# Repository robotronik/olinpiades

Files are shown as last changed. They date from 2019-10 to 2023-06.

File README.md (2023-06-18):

# Git pour les yeux du char des ol'INPiade

## Installation du dépot :
Pour cloner ce dépot:
```
git clone --recurse-submodules git@github.com:robotronik/olinpiades.git
```
## pré-requis : 
 
### Programmation
- arm-none-eabi-gcc: pour compiler le programme du stm32 ainsi que ces librairies (arm-none-eabi-**** sur arch linux)
- openocd: pour envoyer le programme au stm32
- meson pour compiler
### Génération des images
- Python
### Carte élctronique : 
- kicad 5

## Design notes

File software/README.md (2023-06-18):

# Programme des matrices de LEDs pour les olinpiades
Pour cloner ce dépot:
```
git clone --recurse-submodules git@github.com:robotronik/olinpiades.git
```
## Programme du stm32
pré-requis:  
- arm-none-eabi-gcc: pour compiler le programme du stm32 ainsi que ces librairies (arm-none-eabi-**** sur arch linux)
- openocd: pour envoyer le programme au stm32
- meson pour compiler

Pour compiler les programmes:
```
make build
```
Le dossier build est alors créé. Pour envoyer le programme au stm32 (cela nécessite d'avoir installé les règles udev correctement (make install_udev)), depuis le dossier \_build:
```
ninja olinpiades.flash
```

## Programme de génération de frames
Pour tester ce qui va être afficher, depuis le dossier \_build:
```
./frames_generator/display_test
```
Si les frames ont étés modifiées (options de génération ou images d'entrée):
```
ninja regenerate_frames_files
ninja
```
Les frames sont stockées dans le fichier frames_generator/frames_definition.c . Le script python frames_generator/generator.py est en charge de créer ce fichier. Des options sont disponibles en haut de ce fichier (rotation, miroir x, miroir y, affichage du résultat appliqué à chaque image).  

Les frames sont générées à partir des images contenues dans frames_generator/images. L'ordre alphabétique des fichiers donne l'ordre des frames. La convention de nommage à respecter est la suivante: nomimage_durée_seuil.jpg (ou .png). durée est proportionnel à la durée d'apparition de l'image (entre 0 et 255) et le seuil est celui appliqué à l'image (entre 0 et 255).  

Le programme affiche la taille utilisée pour le stockage de frames (en octets). Le stm32f303k8t6 devrait pouvoir en contenir 70 au minimum.

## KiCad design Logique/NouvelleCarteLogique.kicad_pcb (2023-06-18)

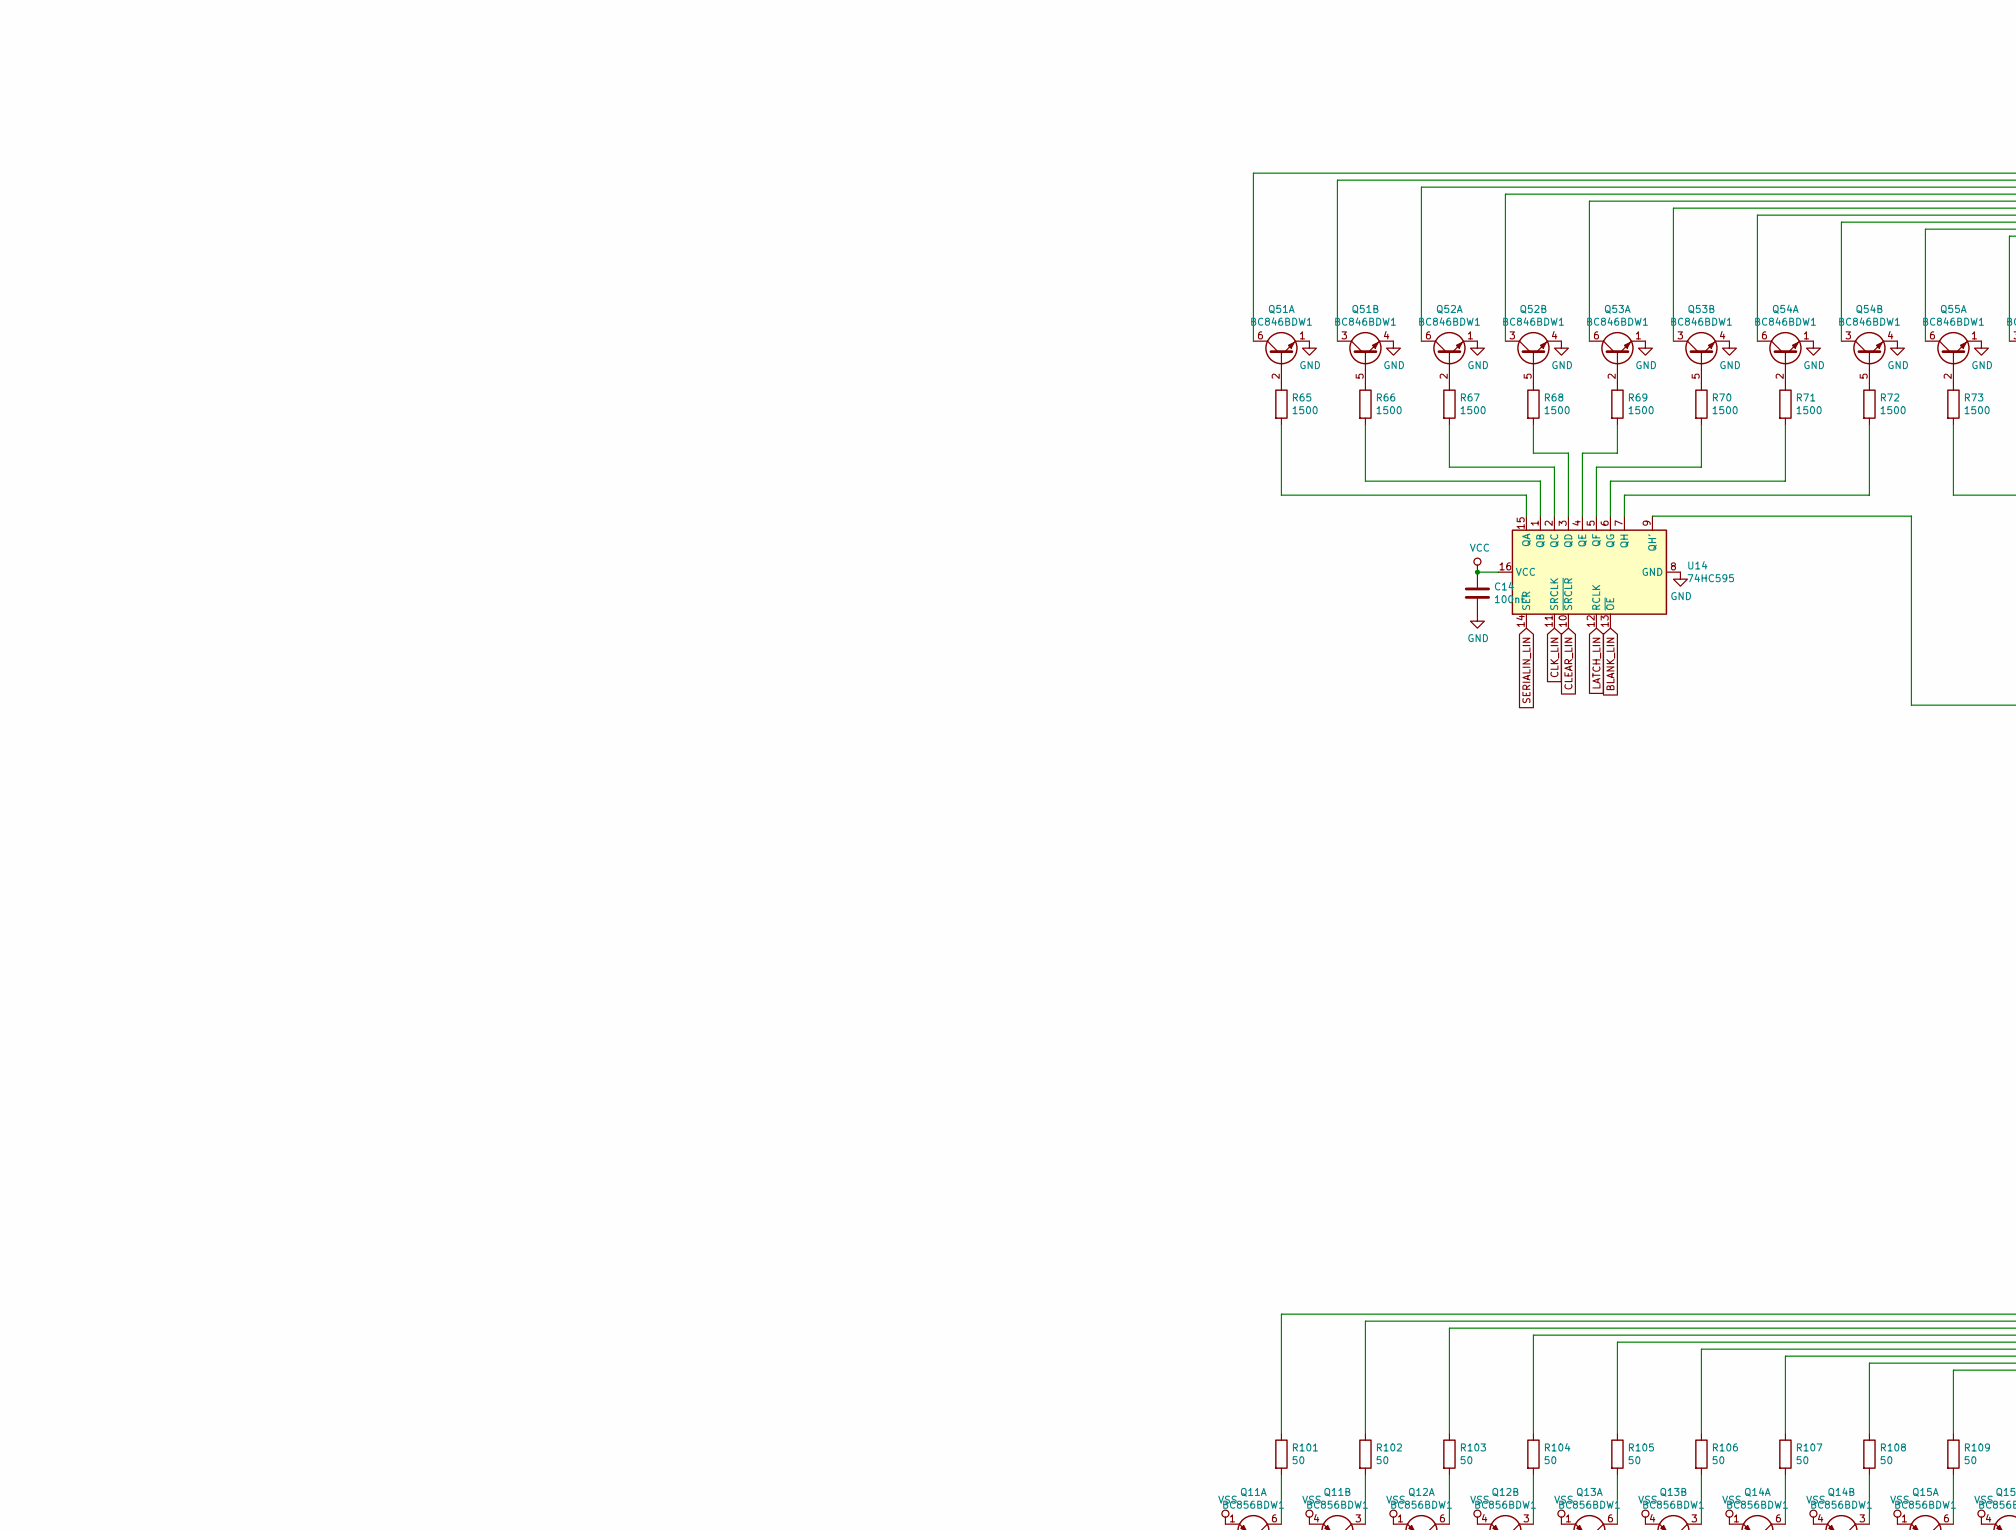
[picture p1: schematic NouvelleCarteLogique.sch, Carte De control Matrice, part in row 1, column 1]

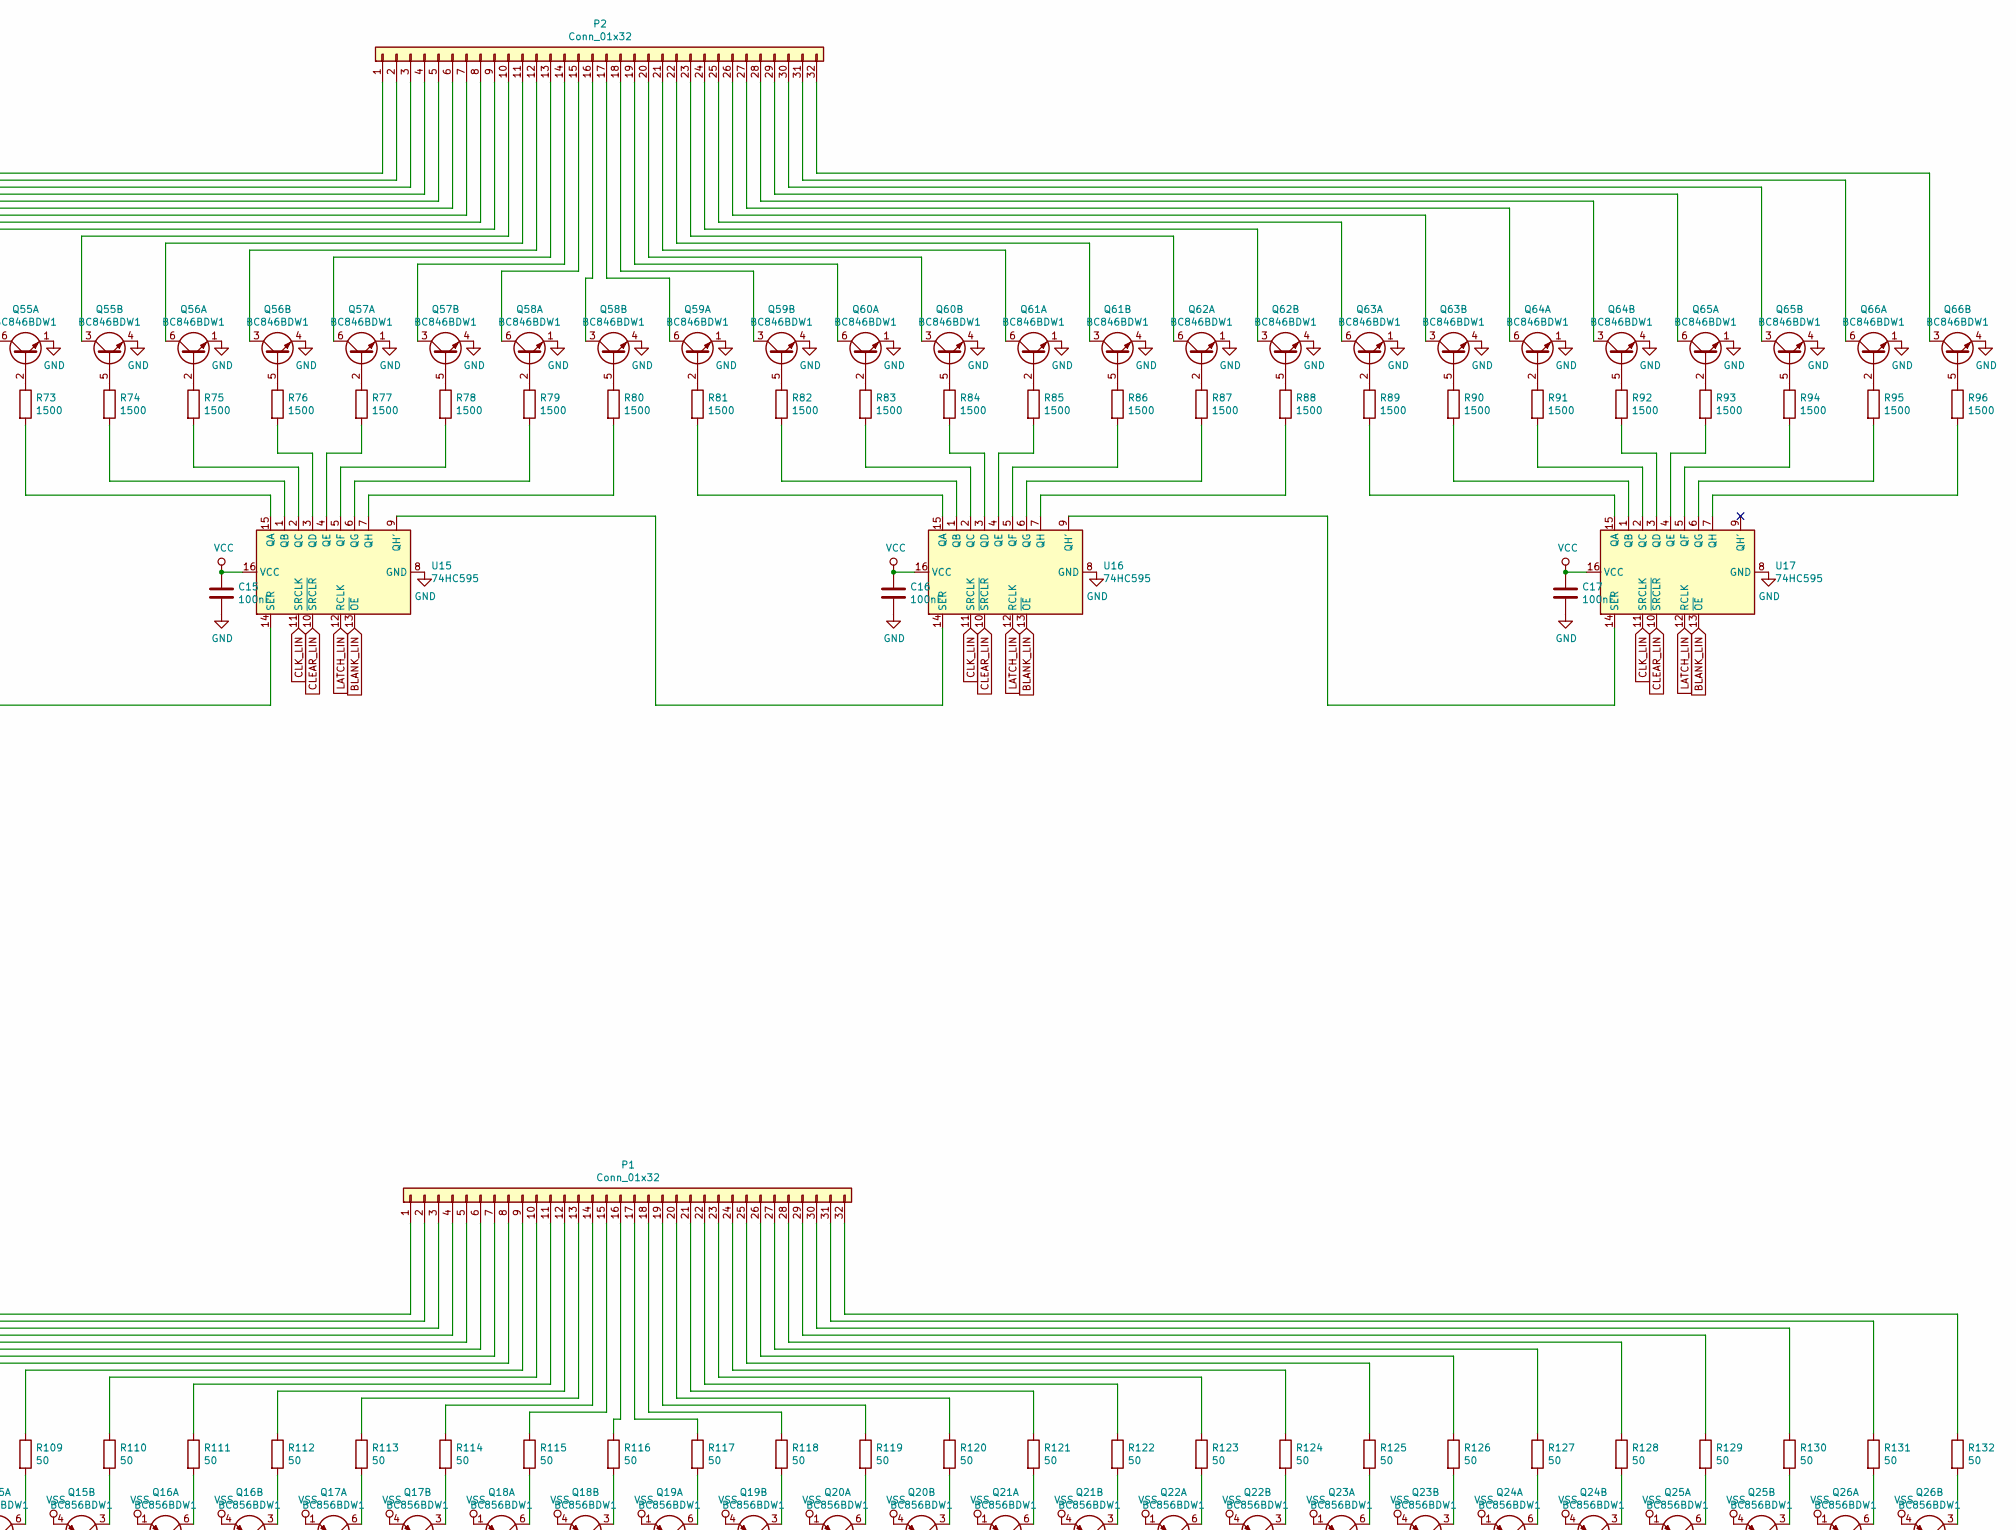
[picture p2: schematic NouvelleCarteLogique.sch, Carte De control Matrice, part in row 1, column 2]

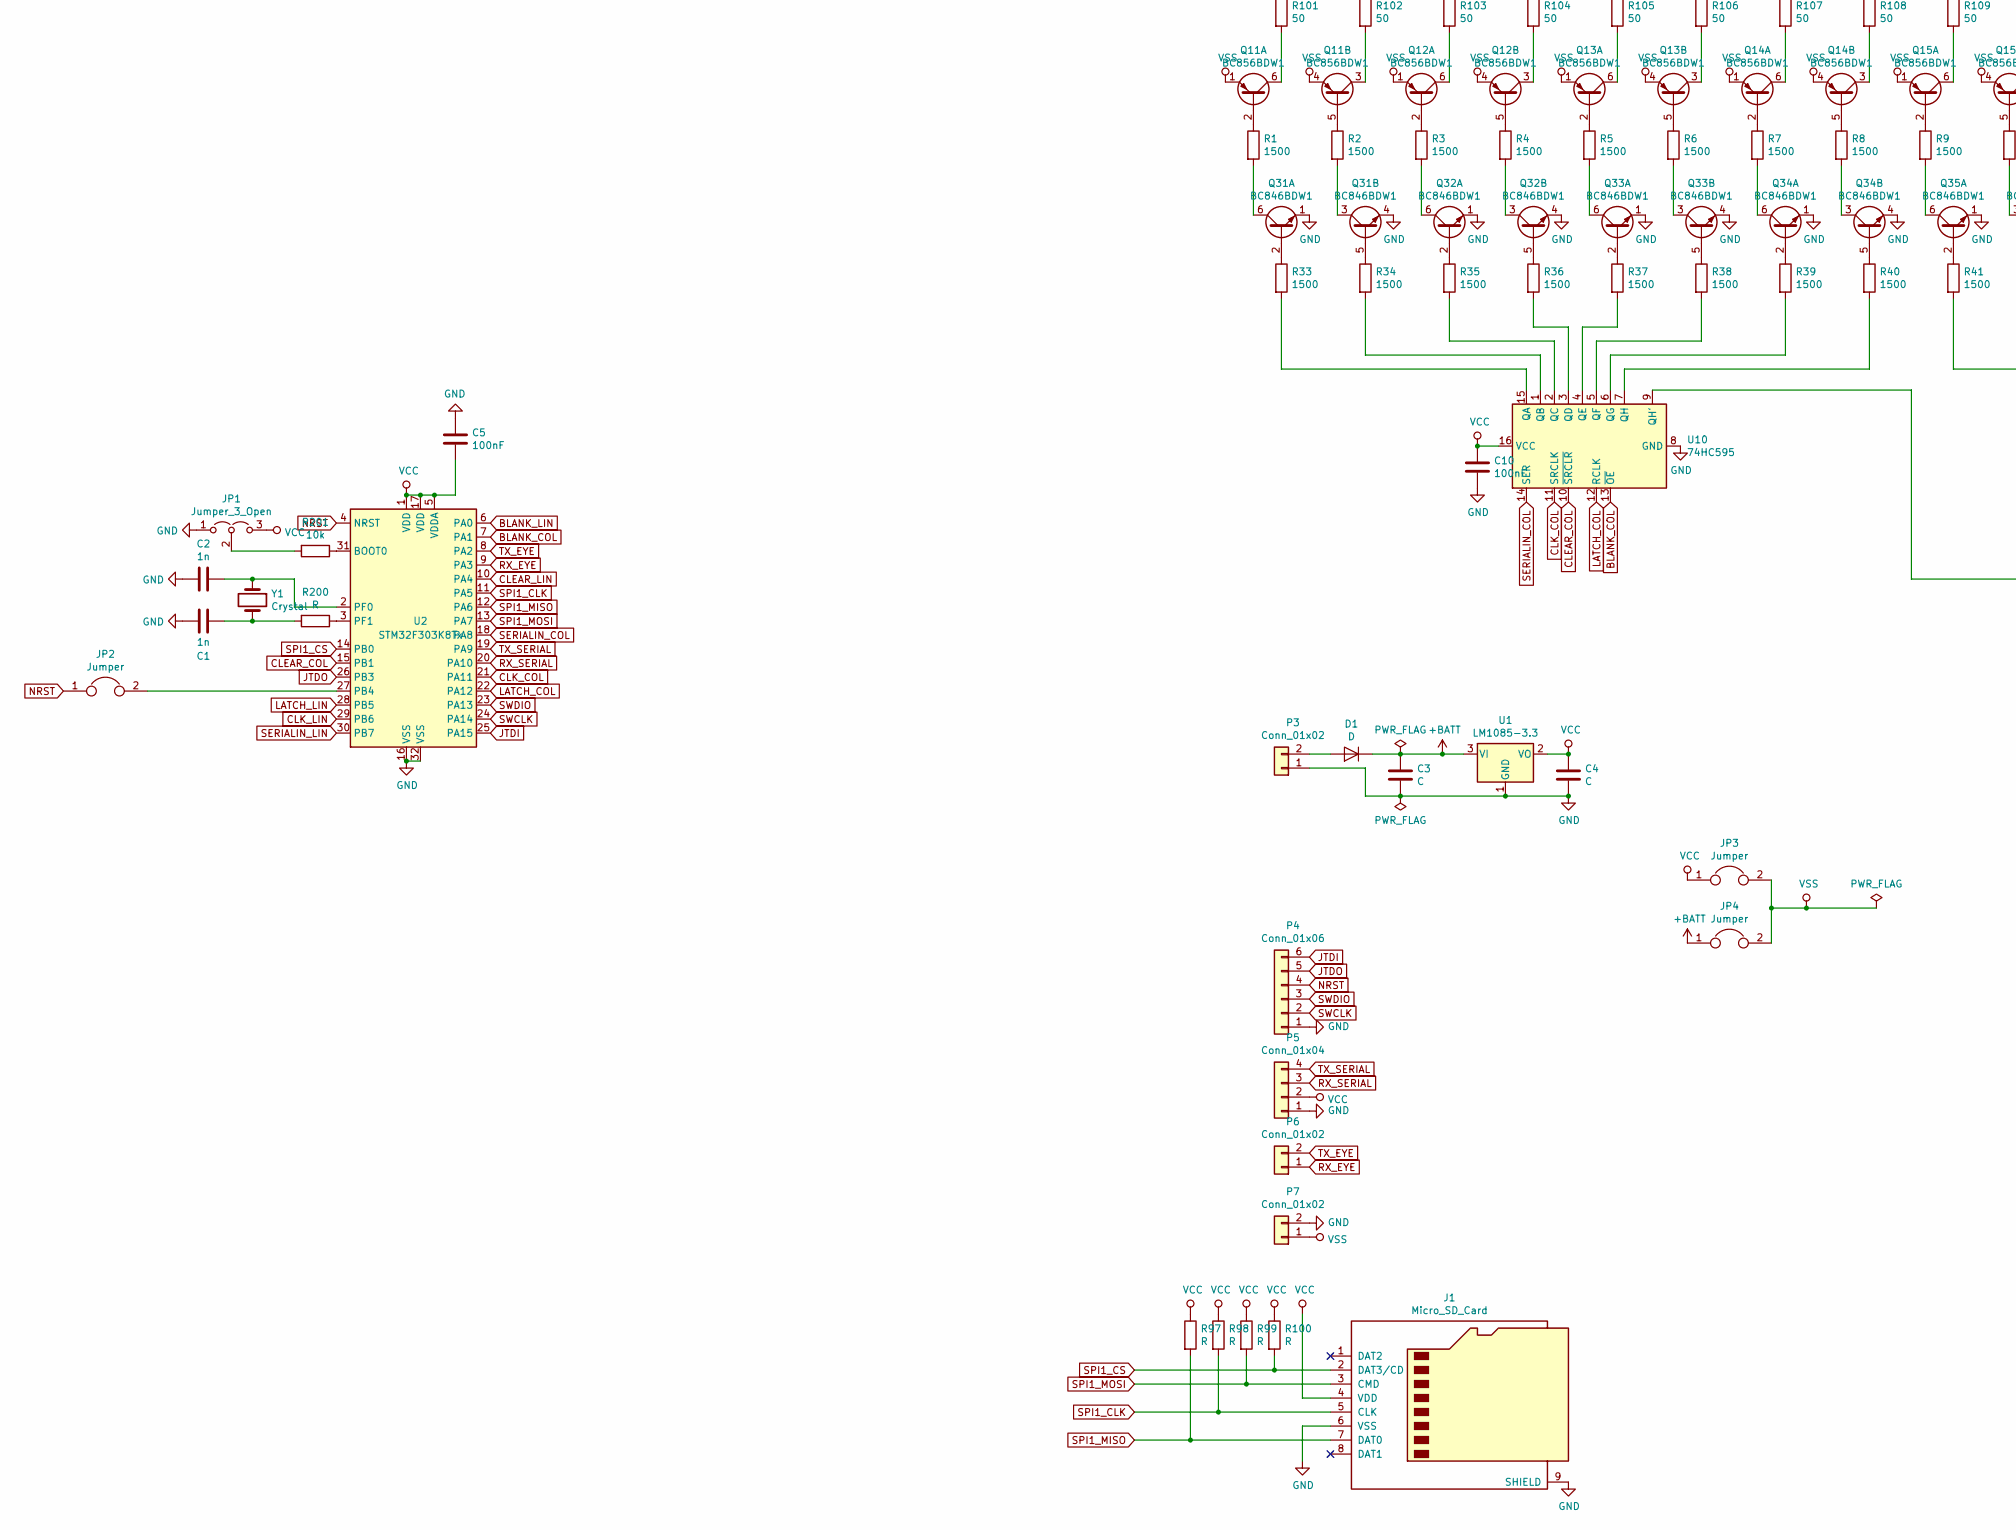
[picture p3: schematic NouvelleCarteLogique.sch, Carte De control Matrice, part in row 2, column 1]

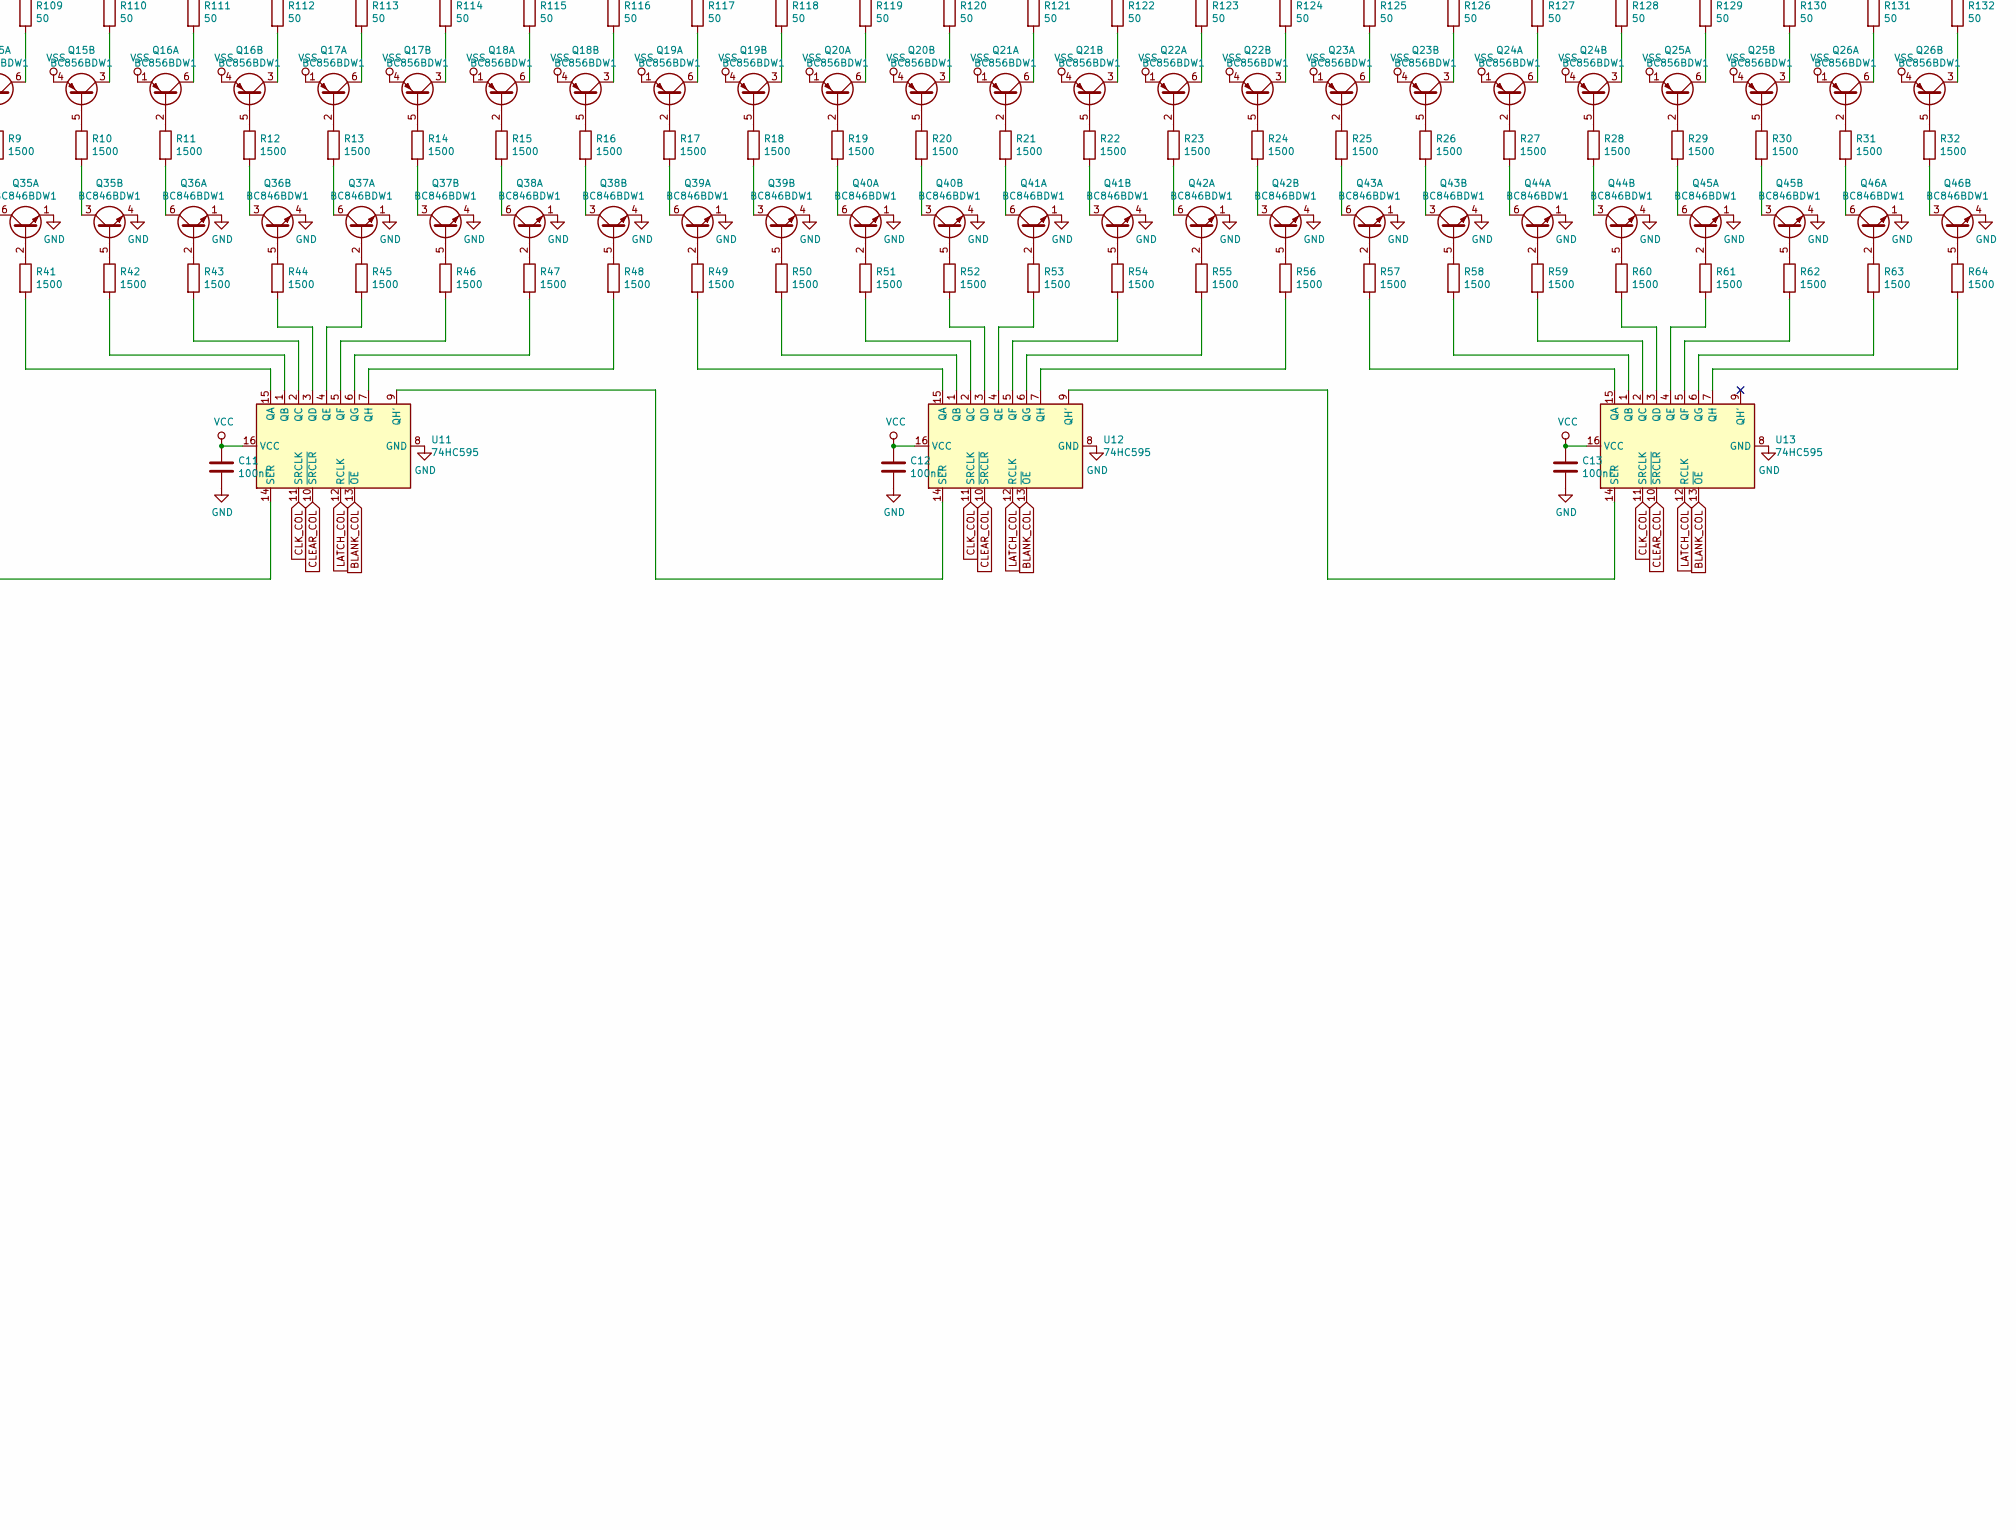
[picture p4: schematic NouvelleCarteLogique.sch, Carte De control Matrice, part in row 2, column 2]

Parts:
C1, C2: 1n; C_0805_2012Metric_Pad1.15x1.40mm_HandSolder
C3, C4: C; C_0805_2012Metric_Pad1.15x1.40mm_HandSolder
C5, C10, C11, C12, C13, C14, C15, C16, C17: 100nF; C_0805_2012Metric_Pad1.15x1.40mm_HandSolder
D1: D; D_SMA_Handsoldering
J1: Micro_SD_Card; microSD_HC_Wuerth_693072010801
JP1: Jumper_3_Open; PinHeader_1x03_P2.54mm_Vertical
JP2, JP3, JP4: Jumper; R_0805_2012Metric_Pad1.15x1.40mm_HandSolder
P1, P2: Conn_01x32; PinHeader_1x32_P2.54mm_Vertical
P3, P6, P7: Conn_01x02; TerminalBlock_bornier-2_P5.08mm
P4: Conn_01x06; PinHeader_1x06_P2.54mm_Horizontal
P5: Conn_01x04; PinHeader_1x04_P2.54mm_Horizontal
Q11, Q12, Q13, Q14, Q15, Q16, Q17, Q18, Q19, Q20, Q21, Q22, Q23, Q24, Q25, Q26: BC856BDW1; SOT-363_SC-70-6
Q31, Q32, Q33, Q34, Q35, Q36, Q37, Q38, Q39, Q40, Q41, Q42, Q43, Q44, Q45, Q46, Q51, Q52, Q53, Q54, Q55, Q56, Q57, Q58, Q59, Q60, Q61, Q62, Q63, Q64, Q65, Q66: BC846BDW1; SOT-363_SC-70-6
R1, R2, R3, R4, R5, R6, R7, R8, R9, R10, R11, R12, R13, R14, R15, R16, R17, R18, R19, R20, R21, R22, R23, R24, R25, R26, R27, R28, R29, R30, R31, R32, R33, R34, R35, R36, R37, R38, R39, R40, R41, R42, R43, R44, R45, R46, R47, R48, R49, R50, R51, R52, R53, R54, R55, R56, R57, R58, R59, R60, R61, R62, R63, R64, R65, R66, R67, R68, R69, R70, R71, R72, R73, R74, R75, R76, R77, R78, R79, R80, R81, R82, R83, R84, R85, R86, R87, R88, R89, R90, R91, R92, R93, R94, R95, R96: 1500; R_0805_2012Metric_Pad1.15x1.40mm_HandSolder
R97, R98, R99, R100, R200: R; R_0805_2012Metric_Pad1.15x1.40mm_HandSolder
R101, R102, R103, R104, R105, R106, R107, R108, R109, R110, R111, R112, R113, R114, R115, R116, R117, R118, R119, R120, R121, R122, R123, R124, R125, R126, R127, R128, R129, R130, R131, R132: 50; R_0805_2012Metric_Pad1.15x1.40mm_HandSolder
R201: 10k; R_0805_2012Metric_Pad1.15x1.40mm_HandSolder
U1: LM1085-3.3; TO-263-3_TabPin2
U2: STM32F303K8Tx; LQFP-32_7x7mm_P0.8mm
U10, U11, U12, U13, U14, U15, U16, U17: 74HC595; TSSOP-16_4.4x5mm_P0.65mm
Y1: Crystal; Crystal_HC49-4H_Vertical

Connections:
+BATT: C3.1, D1.1 (K), JP4.1, U1.3 (VI)
BLANK_COL: U2.7 (PA1), U10.13 (~OE), U11.13 (~OE), U12.13 (~OE), U13.13 (~OE)
BLANK_LIN: U2.6 (PA0), U14.13 (~OE), U15.13 (~OE), U16.13 (~OE), U17.13 (~OE)
CLEAR_COL: U2.15 (PB1), U10.10 (~SRCLR), U11.10 (~SRCLR), U12.10 (~SRCLR), U13.10 (~SRCLR)
CLEAR_LIN: U2.10 (PA4), U14.10 (~SRCLR), U15.10 (~SRCLR), U16.10 (~SRCLR), U17.10 (~SRCLR)
CLK_COL: U2.21 (PA11), U10.11 (SRCLK), U11.11 (SRCLK), U12.11 (SRCLK), U13.11 (SRCLK)
CLK_LIN: U2.29 (PB6), U14.11 (SRCLK), U15.11 (SRCLK), U16.11 (SRCLK), U17.11 (SRCLK)
GND: C1.2, C2.2, C3.2, C4.2, C5.1, C10.2, C11.2, C12.2, C13.2, C14.2, C15.2, C16.2, C17.2, J1.6 (VSS), J1.9 (SHIELD), JP1.1 (A), P3.1, P4.1, P5.1, P7.2, Q31.1 (E1), Q31.4 (E2), Q32.1 (E1), Q32.4 (E2), Q33.1 (E1), Q33.4 (E2), Q34.1 (E1), Q34.4 (E2), Q35.1 (E1), Q35.4 (E2), Q36.1 (E1), Q36.4 (E2), Q37.1 (E1), Q37.4 (E2), Q38.1 (E1), Q38.4 (E2), Q39.1 (E1), Q39.4 (E2), Q40.1 (E1), Q40.4 (E2), Q41.1 (E1), Q41.4 (E2), Q42.1 (E1), Q42.4 (E2), Q43.1 (E1), Q43.4 (E2), Q44.1 (E1), Q44.4 (E2), Q45.1 (E1), Q45.4 (E2), Q46.1 (E1), Q46.4 (E2), Q51.1 (E1), Q51.4 (E2), Q52.1 (E1), Q52.4 (E2), Q53.1 (E1), Q53.4 (E2), Q54.1 (E1), Q54.4 (E2), Q55.1 (E1), Q55.4 (E2), Q56.1 (E1), Q56.4 (E2), Q57.1 (E1), Q57.4 (E2), Q58.1 (E1), Q58.4 (E2), Q59.1 (E1), Q59.4 (E2), Q60.1 (E1), Q60.4 (E2), Q61.1 (E1), Q61.4 (E2), Q62.1 (E1), Q62.4 (E2), Q63.1 (E1), Q63.4 (E2), Q64.1 (E1), Q64.4 (E2), Q65.1 (E1), Q65.4 (E2), Q66.1 (E1), Q66.4 (E2), U1.1 (GND), U2.16 (VSS), U2.32 (VSS), U10.8 (GND), U11.8 (GND), U12.8 (GND), U13.8 (GND), U14.8 (GND), U15.8 (GND), U16.8 (GND), U17.8 (GND)
JTDI: P4.6, U2.25 (PA15)
JTDO: P4.5, U2.26 (PB3)
LATCH_COL: U2.22 (PA12), U10.12 (RCLK), U11.12 (RCLK), U12.12 (RCLK), U13.12 (RCLK)
LATCH_LIN: U2.28 (PB5), U14.12 (RCLK), U15.12 (RCLK), U16.12 (RCLK), U17.12 (RCLK)
NRST: JP2.1, P4.4, U2.4 (NRST)
unnamed: C1.1, R200.2, Y1.2
unnamed: C2.1, U2.2 (PF0), Y1.1
unnamed: D1.2 (A), P3.2
unnamed: JP1.2 (C), R201.2
unnamed: JP2.2, U2.27 (PB4)
unnamed: P1.1, R101.1
unnamed: P1.2, R102.1
unnamed: P1.3, R103.1
unnamed: P1.4, R104.1
unnamed: P1.5, R105.1
unnamed: P1.6, R106.1
unnamed: P1.7, R107.1
unnamed: P1.8, R108.1
unnamed: P1.9, R109.1
unnamed: P1.10, R110.1
unnamed: P1.11, R111.1
unnamed: P1.12, R112.1
unnamed: P1.13, R113.1
unnamed: P1.14, R114.1
unnamed: P1.15, R115.1
unnamed: P1.16, R116.1
unnamed: P1.17, R117.1
unnamed: P1.18, R118.1
unnamed: P1.19, R119.1
unnamed: P1.20, R120.1
unnamed: P1.21, R121.1
unnamed: P1.22, R122.1
unnamed: P1.23, R123.1
unnamed: P1.24, R124.1
unnamed: P1.25, R125.1
unnamed: P1.26, R126.1
unnamed: P1.27, R127.1
unnamed: P1.28, R128.1
unnamed: P1.29, R129.1
unnamed: P1.30, R130.1
unnamed: P1.31, R131.1
unnamed: P1.32, R132.1
unnamed: P2.1, Q51.6 (C1)
unnamed: P2.2, Q51.3 (C2)
unnamed: P2.3, Q52.6 (C1)
unnamed: P2.4, Q52.3 (C2)
unnamed: P2.5, Q53.6 (C1)
unnamed: P2.6, Q53.3 (C2)
unnamed: P2.7, Q54.6 (C1)
unnamed: P2.8, Q54.3 (C2)
unnamed: P2.9, Q55.6 (C1)
unnamed: P2.10, Q55.3 (C2)
unnamed: P2.11, Q56.6 (C1)
unnamed: P2.12, Q56.3 (C2)
unnamed: P2.13, Q57.6 (C1)
unnamed: P2.14, Q57.3 (C2)
unnamed: P2.15, Q58.6 (C1)
unnamed: P2.16, Q58.3 (C2)
unnamed: P2.17, Q59.6 (C1)
unnamed: P2.18, Q59.3 (C2)
unnamed: P2.19, Q60.6 (C1)
unnamed: P2.20, Q60.3 (C2)
unnamed: P2.21, Q61.6 (C1)
unnamed: P2.22, Q61.3 (C2)
unnamed: P2.23, Q62.6 (C1)
unnamed: P2.24, Q62.3 (C2)
unnamed: P2.25, Q63.6 (C1)
unnamed: P2.26, Q63.3 (C2)
unnamed: P2.27, Q64.6 (C1)
unnamed: P2.28, Q64.3 (C2)
unnamed: P2.29, Q65.6 (C1)
unnamed: P2.30, Q65.3 (C2)
unnamed: P2.31, Q66.6 (C1)
unnamed: P2.32, Q66.3 (C2)
unnamed: Q11.2 (B1), R1.1
unnamed: Q11.3 (C2), R102.2
unnamed: Q11.5 (B2), R2.1
unnamed: Q11.6 (C1), R101.2
unnamed: Q12.2 (B1), R3.1
unnamed: Q12.3 (C2), R104.2
unnamed: Q12.5 (B2), R4.1
unnamed: Q12.6 (C1), R103.2
unnamed: Q13.2 (B1), R5.1
unnamed: Q13.3 (C2), R106.2
unnamed: Q13.5 (B2), R6.1
unnamed: Q13.6 (C1), R105.2
unnamed: Q14.2 (B1), R7.1
unnamed: Q14.3 (C2), R108.2
unnamed: Q14.5 (B2), R8.1
unnamed: Q14.6 (C1), R107.2
unnamed: Q15.2 (B1), R9.1
unnamed: Q15.3 (C2), R110.2
unnamed: Q15.5 (B2), R10.1
unnamed: Q15.6 (C1), R109.2
unnamed: Q16.2 (B1), R11.1
unnamed: Q16.3 (C2), R112.2
unnamed: Q16.5 (B2), R12.1
unnamed: Q16.6 (C1), R111.2
unnamed: Q17.2 (B1), R13.1
unnamed: Q17.3 (C2), R114.2
unnamed: Q17.5 (B2), R14.1
unnamed: Q17.6 (C1), R113.2
unnamed: Q18.2 (B1), R15.1
unnamed: Q18.3 (C2), R116.2
unnamed: Q18.5 (B2), R16.1
unnamed: Q18.6 (C1), R115.2
unnamed: Q19.2 (B1), R17.1
unnamed: Q19.3 (C2), R118.2
unnamed: Q19.5 (B2), R18.1
unnamed: Q19.6 (C1), R117.2
unnamed: Q20.2 (B1), R19.1
unnamed: Q20.3 (C2), R120.2
unnamed: Q20.5 (B2), R20.1
unnamed: Q20.6 (C1), R119.2
unnamed: Q21.2 (B1), R21.1
unnamed: Q21.3 (C2), R122.2
unnamed: Q21.5 (B2), R22.1
unnamed: Q21.6 (C1), R121.2
unnamed: Q22.2 (B1), R23.1
unnamed: Q22.3 (C2), R124.2
unnamed: Q22.5 (B2), R24.1
unnamed: Q22.6 (C1), R123.2
unnamed: Q23.2 (B1), R25.1
unnamed: Q23.3 (C2), R126.2
unnamed: Q23.5 (B2), R26.1
unnamed: Q23.6 (C1), R125.2
unnamed: Q24.2 (B1), R27.1
unnamed: Q24.3 (C2), R128.2
unnamed: Q24.5 (B2), R28.1
unnamed: Q24.6 (C1), R127.2
unnamed: Q25.2 (B1), R29.1
unnamed: Q25.3 (C2), R130.2
unnamed: Q25.5 (B2), R30.1
unnamed: Q25.6 (C1), R129.2
unnamed: Q26.2 (B1), R31.1
unnamed: Q26.3 (C2), R132.2
unnamed: Q26.5 (B2), R32.1
unnamed: Q26.6 (C1), R131.2
unnamed: Q31.2 (B1), R33.1
unnamed: Q31.3 (C2), R2.2
unnamed: Q31.5 (B2), R34.1
unnamed: Q31.6 (C1), R1.2
unnamed: Q32.2 (B1), R35.1
unnamed: Q32.3 (C2), R4.2
unnamed: Q32.5 (B2), R36.1
unnamed: Q32.6 (C1), R3.2
unnamed: Q33.2 (B1), R37.1
unnamed: Q33.3 (C2), R6.2
unnamed: Q33.5 (B2), R38.1
unnamed: Q33.6 (C1), R5.2
unnamed: Q34.2 (B1), R39.1
unnamed: Q34.3 (C2), R8.2
unnamed: Q34.5 (B2), R40.1
unnamed: Q34.6 (C1), R7.2
unnamed: Q35.2 (B1), R41.1
unnamed: Q35.3 (C2), R10.2
unnamed: Q35.5 (B2), R42.1
unnamed: Q35.6 (C1), R9.2
unnamed: Q36.2 (B1), R43.1
unnamed: Q36.3 (C2), R12.2
unnamed: Q36.5 (B2), R44.1
unnamed: Q36.6 (C1), R11.2
unnamed: Q37.2 (B1), R45.1
unnamed: Q37.3 (C2), R14.2
unnamed: Q37.5 (B2), R46.1
unnamed: Q37.6 (C1), R13.2
unnamed: Q38.2 (B1), R47.1
unnamed: Q38.3 (C2), R16.2
unnamed: Q38.5 (B2), R48.1
unnamed: Q38.6 (C1), R15.2
unnamed: Q39.2 (B1), R49.1
unnamed: Q39.3 (C2), R18.2
unnamed: Q39.5 (B2), R50.1
unnamed: Q39.6 (C1), R17.2
unnamed: Q40.2 (B1), R51.1
unnamed: Q40.3 (C2), R20.2
unnamed: Q40.5 (B2), R52.1
unnamed: Q40.6 (C1), R19.2
unnamed: Q41.2 (B1), R53.1
unnamed: Q41.3 (C2), R22.2
unnamed: Q41.5 (B2), R54.1
unnamed: Q41.6 (C1), R21.2
unnamed: Q42.2 (B1), R55.1
unnamed: Q42.3 (C2), R24.2
unnamed: Q42.5 (B2), R56.1
unnamed: Q42.6 (C1), R23.2
unnamed: Q43.2 (B1), R57.1
unnamed: Q43.3 (C2), R26.2
unnamed: Q43.5 (B2), R58.1
unnamed: Q43.6 (C1), R25.2
unnamed: Q44.2 (B1), R59.1
unnamed: Q44.3 (C2), R28.2
unnamed: Q44.5 (B2), R60.1
unnamed: Q44.6 (C1), R27.2
unnamed: Q45.2 (B1), R61.1
unnamed: Q45.3 (C2), R30.2
unnamed: Q45.5 (B2), R62.1
unnamed: Q45.6 (C1), R29.2
unnamed: Q46.2 (B1), R63.1
unnamed: Q46.3 (C2), R32.2
unnamed: Q46.5 (B2), R64.1
unnamed: Q46.6 (C1), R31.2
unnamed: Q51.2 (B1), R65.1
unnamed: Q51.5 (B2), R66.1
unnamed: Q52.2 (B1), R67.1
unnamed: Q52.5 (B2), R68.1
unnamed: Q53.2 (B1), R69.1
unnamed: Q53.5 (B2), R70.1
unnamed: Q54.2 (B1), R71.1
unnamed: Q54.5 (B2), R72.1
unnamed: Q55.2 (B1), R73.1
unnamed: Q55.5 (B2), R74.1
unnamed: Q56.2 (B1), R75.1
unnamed: Q56.5 (B2), R76.1
unnamed: Q57.2 (B1), R77.1
unnamed: Q57.5 (B2), R78.1
unnamed: Q58.2 (B1), R79.1
unnamed: Q58.5 (B2), R80.1
unnamed: Q59.2 (B1), R81.1
unnamed: Q59.5 (B2), R82.1
unnamed: Q60.2 (B1), R83.1
unnamed: Q60.5 (B2), R84.1
unnamed: Q61.2 (B1), R85.1
unnamed: Q61.5 (B2), R86.1
unnamed: Q62.2 (B1), R87.1
unnamed: Q62.5 (B2), R88.1
unnamed: Q63.2 (B1), R89.1
unnamed: Q63.5 (B2), R90.1
unnamed: Q64.2 (B1), R91.1
unnamed: Q64.5 (B2), R92.1
unnamed: Q65.2 (B1), R93.1
unnamed: Q65.5 (B2), R94.1
unnamed: Q66.2 (B1), R95.1
unnamed: Q66.5 (B2), R96.1
unnamed: R33.2, U10.15 (QA)
unnamed: R34.2, U10.1 (QB)
unnamed: R35.2, U10.2 (QC)
unnamed: R36.2, U10.3 (QD)
unnamed: R37.2, U10.4 (QE)
unnamed: R38.2, U10.5 (QF)
unnamed: R39.2, U10.6 (QG)
unnamed: R40.2, U10.7 (QH)
unnamed: R41.2, U11.15 (QA)
unnamed: R42.2, U11.1 (QB)
unnamed: R43.2, U11.2 (QC)
unnamed: R44.2, U11.3 (QD)
unnamed: R45.2, U11.4 (QE)
unnamed: R46.2, U11.5 (QF)
unnamed: R47.2, U11.6 (QG)
unnamed: R48.2, U11.7 (QH)
unnamed: R49.2, U12.15 (QA)
unnamed: R50.2, U12.1 (QB)
unnamed: R51.2, U12.2 (QC)
unnamed: R52.2, U12.3 (QD)
unnamed: R53.2, U12.4 (QE)
unnamed: R54.2, U12.5 (QF)
unnamed: R55.2, U12.6 (QG)
unnamed: R56.2, U12.7 (QH)
unnamed: R57.2, U13.15 (QA)
unnamed: R58.2, U13.1 (QB)
unnamed: R59.2, U13.2 (QC)
unnamed: R60.2, U13.3 (QD)
unnamed: R61.2, U13.4 (QE)
unnamed: R62.2, U13.5 (QF)
unnamed: R63.2, U13.6 (QG)
unnamed: R64.2, U13.7 (QH)
unnamed: R65.2, U14.15 (QA)
unnamed: R66.2, U14.1 (QB)
unnamed: R67.2, U14.2 (QC)
unnamed: R68.2, U14.3 (QD)
unnamed: R69.2, U14.4 (QE)
unnamed: R70.2, U14.5 (QF)
unnamed: R71.2, U14.6 (QG)
unnamed: R72.2, U14.7 (QH)
unnamed: R73.2, U15.15 (QA)
unnamed: R74.2, U15.1 (QB)
unnamed: R75.2, U15.2 (QC)
unnamed: R76.2, U15.3 (QD)
unnamed: R77.2, U15.4 (QE)
unnamed: R78.2, U15.5 (QF)
unnamed: R79.2, U15.6 (QG)
unnamed: R80.2, U15.7 (QH)
unnamed: R81.2, U16.15 (QA)
unnamed: R82.2, U16.1 (QB)
unnamed: R83.2, U16.2 (QC)
unnamed: R84.2, U16.3 (QD)
unnamed: R85.2, U16.4 (QE)
unnamed: R86.2, U16.5 (QF)
unnamed: R87.2, U16.6 (QG)
unnamed: R88.2, U16.7 (QH)
unnamed: R89.2, U17.15 (QA)
unnamed: R90.2, U17.1 (QB)
unnamed: R91.2, U17.2 (QC)
unnamed: R92.2, U17.3 (QD)
unnamed: R93.2, U17.4 (QE)
unnamed: R94.2, U17.5 (QF)
unnamed: R95.2, U17.6 (QG)
unnamed: R96.2, U17.7 (QH)
unnamed: R200.1, U2.3 (PF1)
unnamed: R201.1, U2.31 (BOOT0)
unnamed: U10.9 (QH'), U11.14 (SER)
unnamed: U11.9 (QH'), U12.14 (SER)
unnamed: U12.9 (QH'), U13.14 (SER)
unnamed: U14.9 (QH'), U15.14 (SER)
unnamed: U15.9 (QH'), U16.14 (SER)
unnamed: U16.9 (QH'), U17.14 (SER)
RX_EYE: P6.1, U2.9 (PA3)
RX_SERIAL: P5.3, U2.20 (PA10)
SERIALIN_COL: U2.18 (PA8), U10.14 (SER)
SERIALIN_LIN: U2.30 (PB7), U14.14 (SER)
SPI1_CLK: J1.5 (CLK), R98.2, U2.11 (PA5)
SPI1_CS: J1.2 (DAT3/CD), R100.2, U2.14 (PB0)
SPI1_MISO: J1.7 (DAT0), R97.2, U2.12 (PA6)
SPI1_MOSI: J1.3 (CMD), R99.2, U2.13 (PA7)
SWCLK: P4.2, U2.24 (PA14)
SWDIO: P4.3, U2.23 (PA13)
TX_EYE: P6.2, U2.8 (PA2)
TX_SERIAL: P5.4, U2.19 (PA9)
VCC: C4.1, C5.2, C10.1, C11.1, C12.1, C13.1, C14.1, C15.1, C16.1, C17.1, J1.4 (VDD), JP1.3 (B), JP3.1, P5.2, R97.1, R98.1, R99.1, R100.1, U1.2 (VO), U2.1 (VDD), U2.5 (VDDA), U2.17 (VDD), U10.16 (VCC), U11.16 (VCC), U12.16 (VCC), U13.16 (VCC), U14.16 (VCC), U15.16 (VCC), U16.16 (VCC), U17.16 (VCC)
VSS: JP3.2, JP4.2, P7.1, Q11.1 (E1), Q11.4 (E2), Q12.1 (E1), Q12.4 (E2), Q13.1 (E1), Q13.4 (E2), Q14.1 (E1), Q14.4 (E2), Q15.1 (E1), Q15.4 (E2), Q16.1 (E1), Q16.4 (E2), Q17.1 (E1), Q17.4 (E2), Q18.1 (E1), Q18.4 (E2), Q19.1 (E1), Q19.4 (E2), Q20.1 (E1), Q20.4 (E2), Q21.1 (E1), Q21.4 (E2), Q22.1 (E1), Q22.4 (E2), Q23.1 (E1), Q23.4 (E2), Q24.1 (E1), Q24.4 (E2), Q25.1 (E1), Q25.4 (E2), Q26.1 (E1), Q26.4 (E2)

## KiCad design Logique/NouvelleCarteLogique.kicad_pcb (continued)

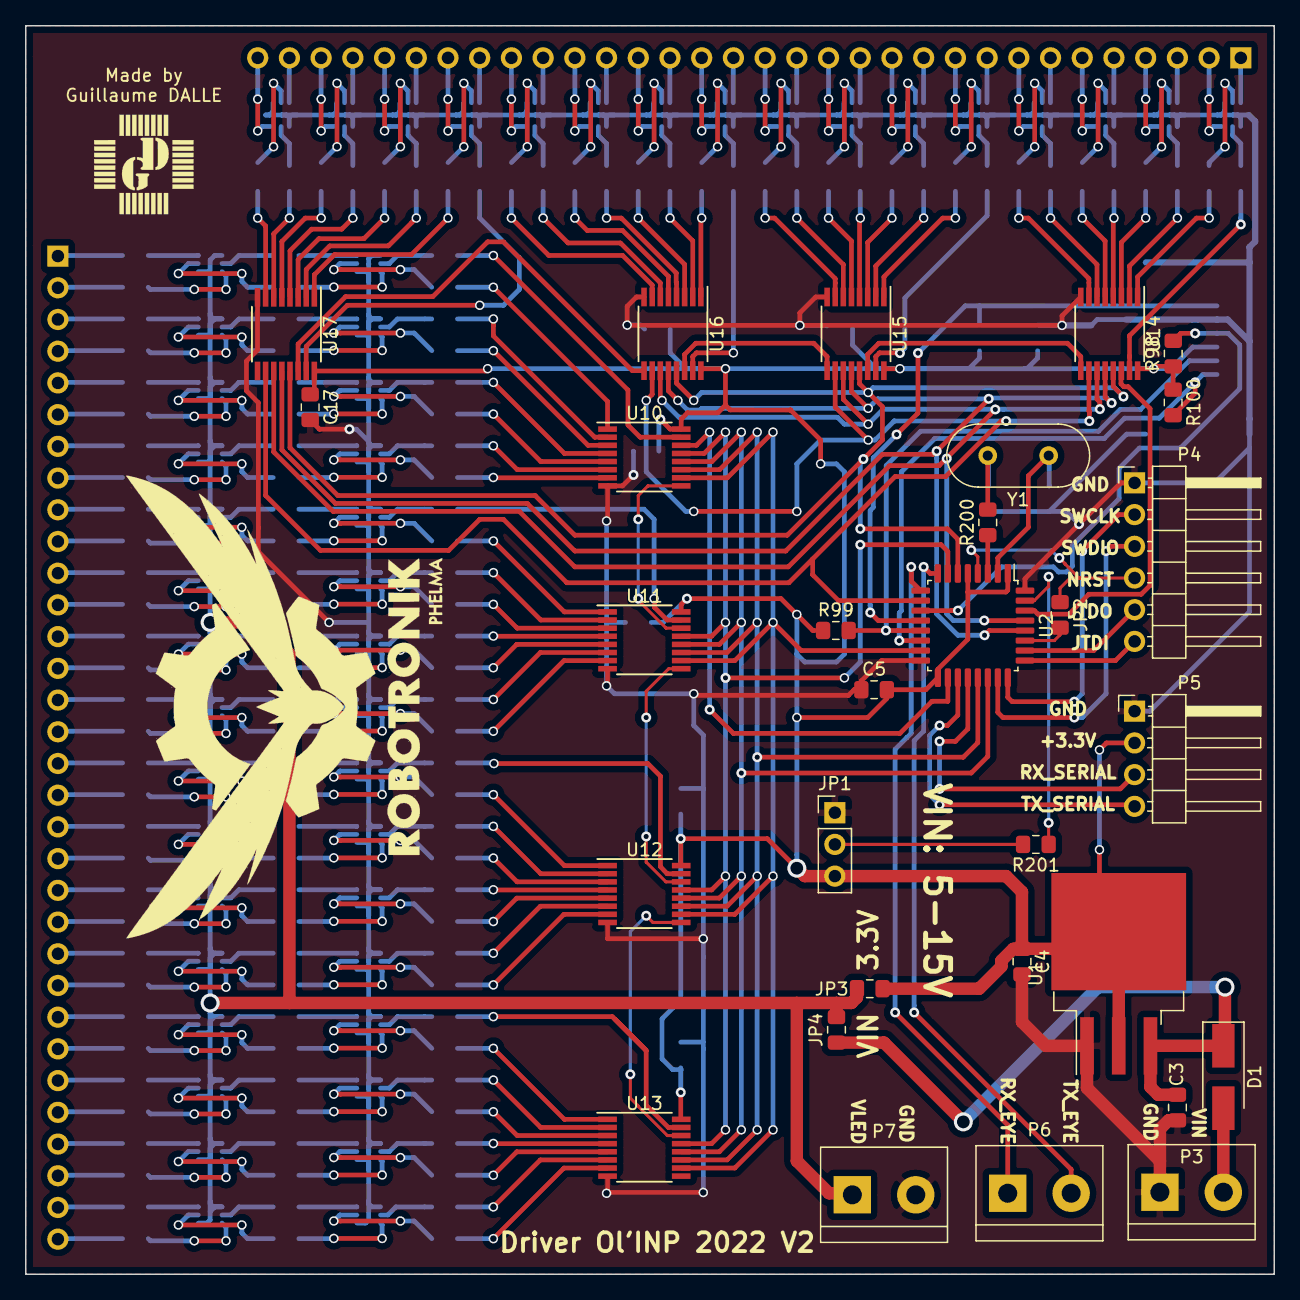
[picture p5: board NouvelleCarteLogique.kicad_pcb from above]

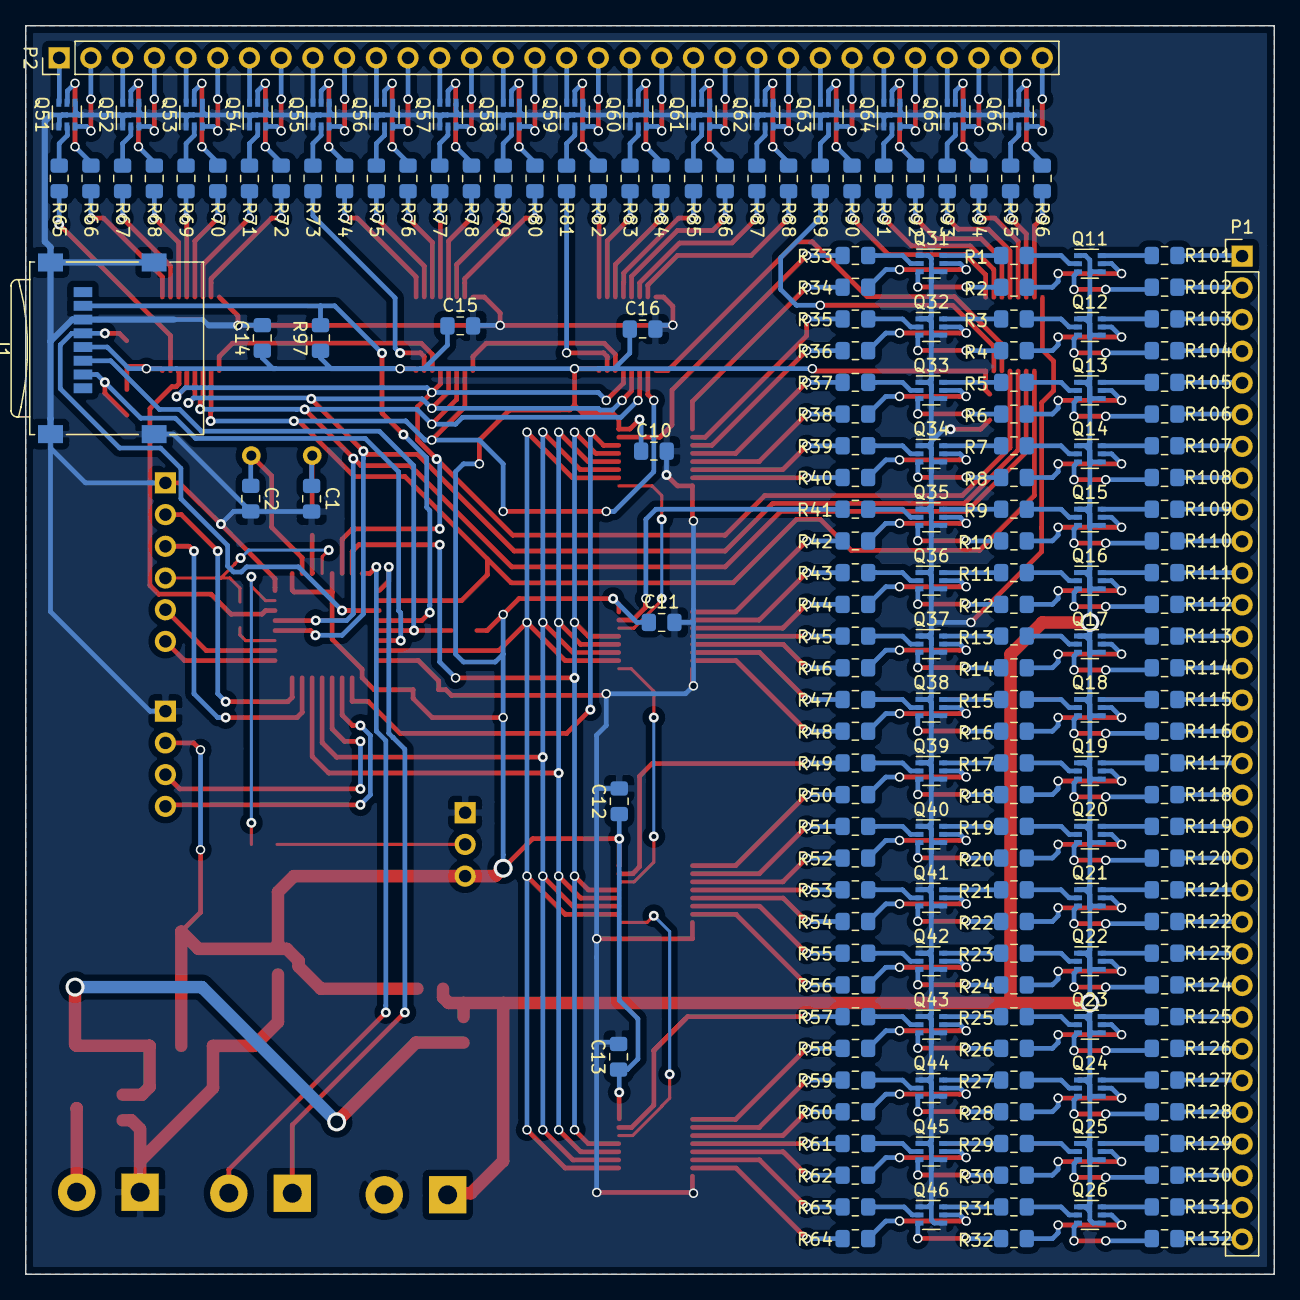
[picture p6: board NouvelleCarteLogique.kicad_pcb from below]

Board: 2 copper layers, 100.0 x 100.0 mm, 219 parts (189 on the bottom side), 328 nets.

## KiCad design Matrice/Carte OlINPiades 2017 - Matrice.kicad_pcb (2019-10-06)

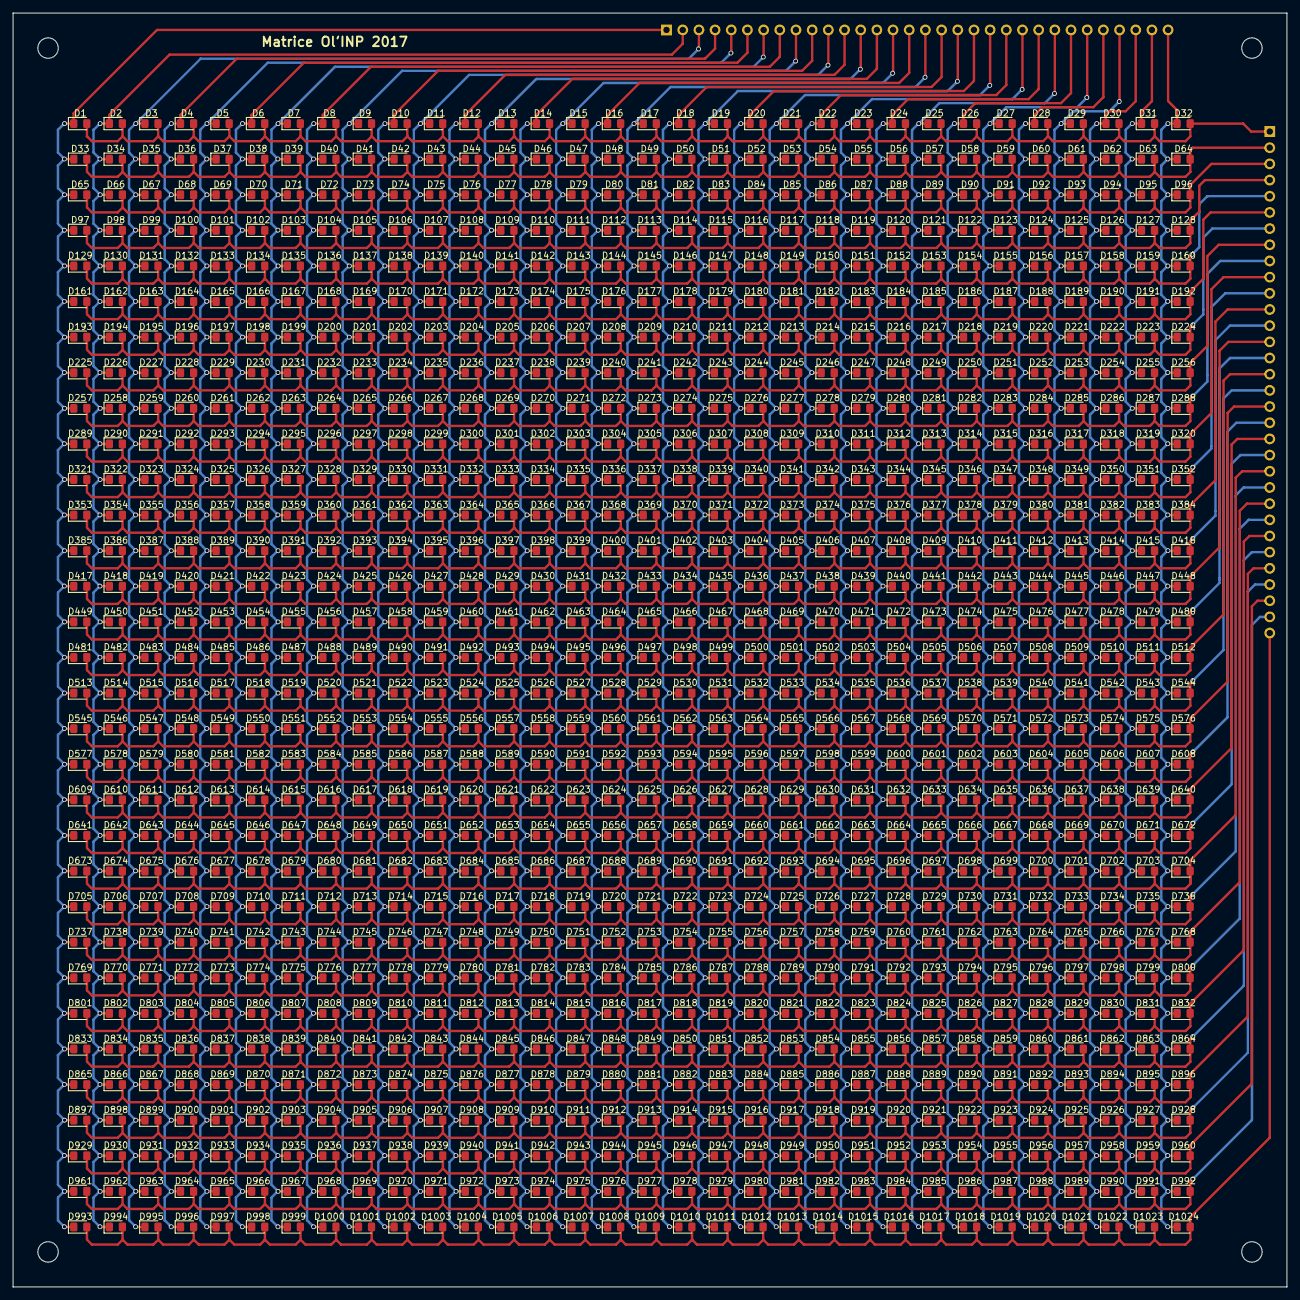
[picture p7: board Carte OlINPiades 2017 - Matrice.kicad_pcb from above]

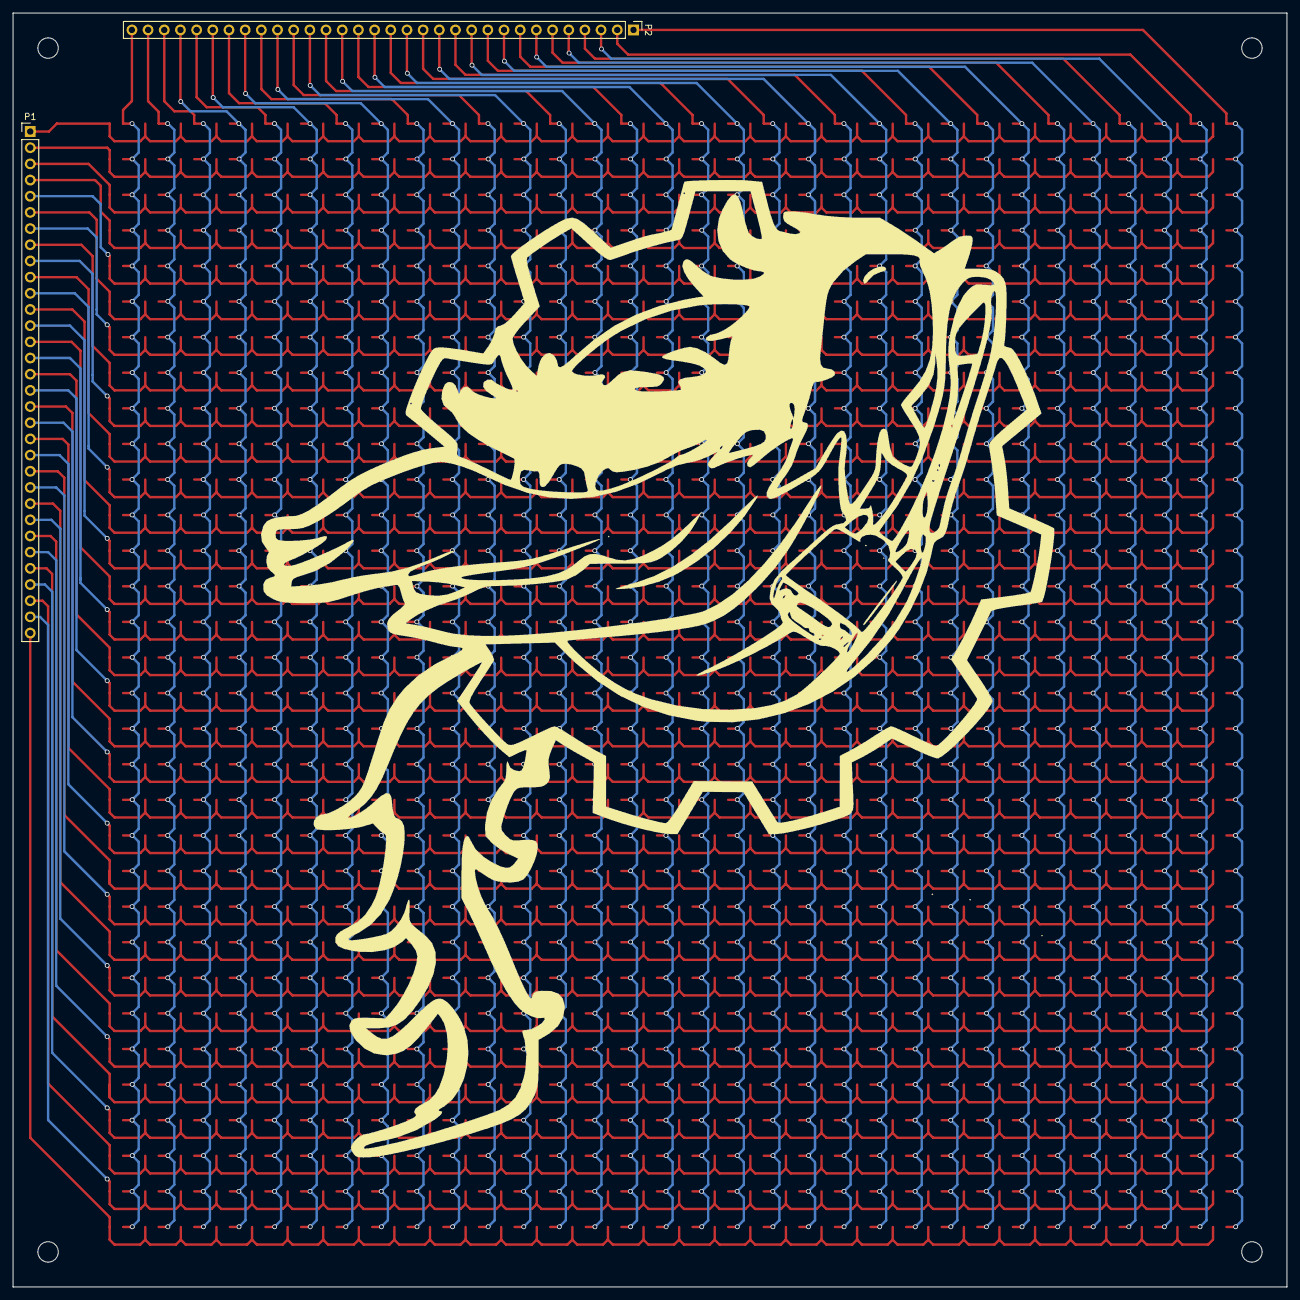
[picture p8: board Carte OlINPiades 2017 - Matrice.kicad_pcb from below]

Board: 2 copper layers, 200.0 x 200.0 mm, 1031 parts (3 on the bottom side), 64 nets.

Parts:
D1, D2, D3, D4, D5, D6, D7, D8, D9, D10, D11, D12, D13, D14, D15, D16, D17, D18, D19, D20, D21, D22, D23, D24, D25, D26, D27, D28, D29, D30, D31, D32, D33, D34, D35, D36, D37, D38, D39, D40, D41, D42, D43, D44, D45, D46, D47, D48, D49, D50, D51, D52, D53, D54, D55, D56, D57, D58, D59, D60, D61, D62, D63, D64, D65, D66, D67, D68, D69, D70, D71, D72, D73, D74, D75, D76, D77, D78, D79, D80, D81, D82, D83, D84, D85, D86, D87, D88, D89, D90, D91, D92, D93, D94, D95, D96, D97, D98, D99, D100, D101, D102, D103, D104, D105, D106, D107, D108, D109, D110, D111, D112, D113, D114, D115, D116, D117, D118, D119, D120, D121, D122, D123, D124, D125, D126, D127, D128, D129, D130, D131, D132, D133, D134, D135, D136, D137, D138, D139, D140, D141, D142, D143, D144, D145, D146, D147, D148, D149, D150, D151, D152, D153, D154, D155, D156, D157, D158, D159, D160, D161, D162, D163, D164, D165, D166, D167, D168, D169, D170, D171, D172, D173, D174, D175, D176, D177, D178, D179, D180, D181, D182, D183, D184, D185, D186, D187, D188, D189, D190, D191, D192, D193, D194, D195, D196, D197, D198, D199, D200, D201, D202, D203, D204, D205, D206, D207, D208, D209, D210, D211, D212, D213, D214, D215, D216, D217, D218, D219, D220, D221, D222, D223, D224, D225, D226, D227, D228, D229, D230, D231, D232, D233, D234, D235, D236, D237, D238, D239, D240, D241, D242, D243, D244, D245, D246, D247, D248, D249, D250, D251, D252, D253, D254, D255, D256, D257, D258, D259, D260, D261, D262, D263, D264, D265, D266, D267, D268, D269, D270, D271, D272, D273, D274, D275, D276, D277, D278, D279, D280, D281, D282, D283, D284, D285, D286, D287, D288, D289, D290, D291, D292, D293, D294, D295, D296, D297, D298, D299, D300, D301, D302, D303, D304, D305, D306, D307, D308, D309, D310, D311, D312, D313, D314, D315, D316, D317, D318, D319, D320, D321, D322, D323, D324, D325, D326, D327, D328, D329, D330, D331, D332, D333, D334, D335, D336, D337, D338, D339, D340, D341, D342, D343, D344, D345, D346, D347, D348, D349, D350, D351, D352, D353, D354, D355, D356, D357, D358, D359, D360, D361, D362, D363, D364, D365, D366, D367, D368, D369, D370, D371, D372, D373, D374, D375, D376, D377, D378, D379, D380, D381, D382, D383, D384, D385, D386, D387, D388, D389, D390, D391, D392, D393, D394, D395, D396, D397, D398, D399, D400, D401, D402, D403, D404, D405, D406, D407, D408, D409, D410, D411, D412, D413, D414, D415, D416, D417, D418, D419, D420, D421, D422, D423, D424, D425, D426, D427, D428, D429, D430, D431, D432, D433, D434, D435, D436, D437, D438, D439, D440, D441, D442, D443, D444, D445, D446, D447, D448, D449, D450, D451, D452, D453, D454, D455, D456, D457, D458, D459, D460, D461, D462, D463, D464, D465, D466, D467, D468, D469, D470, D471, D472, D473, D474, D475, D476, D477, D478, D479, D480, D481, D482, D483, D484, D485, D486, D487, D488, D489, D490, D491, D492, D493, D494, D495, D496, D497, D498, D499, D500, D501, D502, D503, D504, D505, D506, D507, D508, D509, D510, D511, D512, D513, D514, D515, D516, D517, D518, D519, D520, D521, D522, D523, D524, D525, D526, D527, D528, D529, D530, D531, D532, D533, D534, D535, D536, D537, D538, D539, D540, D541, D542, D543, D544, D545, D546, D547, D548, D549, D550, D551, D552, D553, D554, D555, D556, D557, D558, D559, D560, D561, D562, D563, D564, D565, D566, D567, D568, D569, D570, D571, D572, D573, D574, D575, D576, D577, D578, D579, D580, D581, D582, D583, D584, D585, D586, D587, D588, D589, D590, D591, D592, D593, D594, D595, D596, D597, D598, D599, D600, D601, D602, D603, D604, D605, D606, D607, D608, D609, D610, D611, D612, D613, D614, D615, D616, D617, D618, D619, D620, D621, D622, D623, D624, D625, D626, D627, D628, D629, D630, D631, D632, D633, D634, D635, D636, D637, D638, D639, D640, D641, D642, D643, D644, D645, D646, D647, D648, D649, D650, D651, D652, D653, D654, D655, D656, D657, D658, D659, D660, D661, D662, D663, D664, D665, D666, D667, D668, D669, D670, D671, D672, D673, D674, D675, D676, D677, D678, D679, D680, D681, D682, D683, D684, D685, D686, D687, D688, D689, D690, D691, D692, D693, D694, D695, D696, D697, D698, D699, D700, D701, D702, D703, D704, D705, D706, D707, D708, D709, D710, D711, D712, D713, D714, D715, D716, D717, D718, D719, D720, D721, D722, D723, D724, D725, D726, D727, D728, D729, D730, D731, D732, D733, D734, D735, D736, D737, D738, D739, D740, D741, D742, D743, D744, D745, D746, D747, D748, D749, D750, D751, D752, D753, D754, D755, D756, D757, D758, D759, D760, D761, D762, D763, D764, D765, D766, D767, D768, D769, D770, D771, D772, D773, D774, D775, D776, D777, D778, D779, D780, D781, D782, D783, D784, D785, D786, D787, D788, D789, D790, D791, D792, D793, D794, D795, D796, D797, D798, D799, D800, D801, D802, D803, D804, D805, D806, D807, D808, D809, D810, D811, D812, D813, D814, D815, D816, D817, D818, D819, D820, D821, D822, D823, D824, D825, D826, D827, D828, D829, D830, D831, D832, D833, D834, D835, D836, D837, D838, D839, D840, D841, D842, D843, D844, D845, D846, D847, D848, D849, D850, D851, D852, D853, D854, D855, D856, D857, D858, D859, D860, D861, D862, D863, D864, D865, D866, D867, D868, D869, D870, D871, D872, D873, D874, D875, D876, D877, D878, D879, D880, D881, D882, D883, D884, D885, D886, D887, D888, D889, D890, D891, D892, D893, D894, D895, D896, D897, D898, D899, D900, D901, D902, D903, D904, D905, D906, D907, D908, D909, D910, D911, D912, D913, D914, D915, D916, D917, D918, D919, D920, D921, D922, D923, D924, D925, D926, D927, D928, D929, D930, D931, D932, D933, D934, D935, D936, D937, D938, D939, D940, D941, D942, D943, D944, D945, D946, D947, D948, D949, D950, D951, D952, D953, D954, D955, D956, D957, D958, D959, D960, D961, D962, D963, D964, D965, D966, D967, D968, D969, D970, D971, D972, D973, D974, D975, D976, D977, D978, D979, D980, D981, D982, D983, D984, D985, D986, D987, D988, D989, D990, D991, D992, D993, D994, D995, D996, D997, D998, D999, D1000, D1001, D1002, D1003, D1004, D1005, D1006, D1007, D1008, D1009, D1010, D1011, D1012, D1013, D1014, D1015, D1016, D1017, D1018, D1019, D1020, D1021, D1022, D1023, D1024: LED; LED_0805_2012Metric_Pad1.15x1.40mm_HandSolder
LOGO1: Logo_Open_Hardware_Small; robotronik_logo_big
P1, P2: CONN_01X32; PinHeader_1x32_P2.54mm_Vertical
PAD1, PAD2, PAD3, PAD4: MountingHole; MountingHole_3.2mm_M3

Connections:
unnamed: D1.1, D33.1, D65.1, D97.1, D129.1, D161.1, D193.1, D225.1, D257.1, D289.1, D321.1, D353.1, D385.1, D417.1, D449.1, D481.1, D513.1, D545.1, D577.1, D609.1, D641.1, D673.1, D705.1, D737.1, D769.1, D801.1, D833.1, D865.1, D897.1, D929.1, D961.1, D993.1, P2.1
unnamed: D1.2, D2.2, D3.2, D4.2, D5.2, D6.2, D7.2, D8.2, D9.2, D10.2, D11.2, D12.2, D13.2, D14.2, D15.2, D16.2, D17.2, D18.2, D19.2, D20.2, D21.2, D22.2, D23.2, D24.2, D25.2, D26.2, D27.2, D28.2, D29.2, D30.2, D31.2, D32.2, P1.1
unnamed: D10.1, D42.1, D74.1, D106.1, D138.1, D170.1, D202.1, D234.1, D266.1, D298.1, D330.1, D362.1, D394.1, D426.1, D458.1, D490.1, D522.1, D554.1, D586.1, D618.1, D650.1, D682.1, D714.1, D746.1, D778.1, D810.1, D842.1, D874.1, D906.1, D938.1, D970.1, D1002.1, P2.10
unnamed: D33.2, D34.2, D35.2, D36.2, D37.2, D38.2, D39.2, D40.2, D41.2, D42.2, D43.2, D44.2, D45.2, D46.2, D47.2, D48.2, D49.2, D50.2, D51.2, D52.2, D53.2, D54.2, D55.2, D56.2, D57.2, D58.2, D59.2, D60.2, D61.2, D62.2, D63.2, D64.2, P1.2
unnamed: D65.2, D66.2, D67.2, D68.2, D69.2, D70.2, D71.2, D72.2, D73.2, D74.2, D75.2, D76.2, D77.2, D78.2, D79.2, D80.2, D81.2, D82.2, D83.2, D84.2, D85.2, D86.2, D87.2, D88.2, D89.2, D90.2, D91.2, D92.2, D93.2, D94.2, D95.2, D96.2, P1.3
unnamed: D4.1, D36.1, D68.1, D100.1, D132.1, D164.1, D196.1, D228.1, D260.1, D292.1, D324.1, D356.1, D388.1, D420.1, D452.1, D484.1, D516.1, D548.1, D580.1, D612.1, D644.1, D676.1, D708.1, D740.1, D772.1, D804.1, D836.1, D868.1, D900.1, D932.1, D964.1, D996.1, P2.4
unnamed: D97.2, D98.2, D99.2, D100.2, D101.2, D102.2, D103.2, D104.2, D105.2, D106.2, D107.2, D108.2, D109.2, D110.2, D111.2, D112.2, D113.2, D114.2, D115.2, D116.2, D117.2, D118.2, D119.2, D120.2, D121.2, D122.2, D123.2, D124.2, D125.2, D126.2, D127.2, D128.2, P1.4
unnamed: D5.1, D37.1, D69.1, D101.1, D133.1, D165.1, D197.1, D229.1, D261.1, D293.1, D325.1, D357.1, D389.1, D421.1, D453.1, D485.1, D517.1, D549.1, D581.1, D613.1, D645.1, D677.1, D709.1, D741.1, D773.1, D805.1, D837.1, D869.1, D901.1, D933.1, D965.1, D997.1, P2.5
unnamed: D6.1, D38.1, D70.1, D102.1, D134.1, D166.1, D198.1, D230.1, D262.1, D294.1, D326.1, D358.1, D390.1, D422.1, D454.1, D486.1, D518.1, D550.1, D582.1, D614.1, D646.1, D678.1, D710.1, D742.1, D774.1, D806.1, D838.1, D870.1, D902.1, D934.1, D966.1, D998.1, P2.6
unnamed: D7.1, D39.1, D71.1, D103.1, D135.1, D167.1, D199.1, D231.1, D263.1, D295.1, D327.1, D359.1, D391.1, D423.1, D455.1, D487.1, D519.1, D551.1, D583.1, D615.1, D647.1, D679.1, D711.1, D743.1, D775.1, D807.1, D839.1, D871.1, D903.1, D935.1, D967.1, D999.1, P2.7
unnamed: D129.2, D130.2, D131.2, D132.2, D133.2, D134.2, D135.2, D136.2, D137.2, D138.2, D139.2, D140.2, D141.2, D142.2, D143.2, D144.2, D145.2, D146.2, D147.2, D148.2, D149.2, D150.2, D151.2, D152.2, D153.2, D154.2, D155.2, D156.2, D157.2, D158.2, D159.2, D160.2, P1.5
unnamed: D2.1, D34.1, D66.1, D98.1, D130.1, D162.1, D194.1, D226.1, D258.1, D290.1, D322.1, D354.1, D386.1, D418.1, D450.1, D482.1, D514.1, D546.1, D578.1, D610.1, D642.1, D674.1, D706.1, D738.1, D770.1, D802.1, D834.1, D866.1, D898.1, D930.1, D962.1, D994.1, P2.2
unnamed: D3.1, D35.1, D67.1, D99.1, D131.1, D163.1, D195.1, D227.1, D259.1, D291.1, D323.1, D355.1, D387.1, D419.1, D451.1, D483.1, D515.1, D547.1, D579.1, D611.1, D643.1, D675.1, D707.1, D739.1, D771.1, D803.1, D835.1, D867.1, D899.1, D931.1, D963.1, D995.1, P2.3
unnamed: D161.2, D162.2, D163.2, D164.2, D165.2, D166.2, D167.2, D168.2, D169.2, D170.2, D171.2, D172.2, D173.2, D174.2, D175.2, D176.2, D177.2, D178.2, D179.2, D180.2, D181.2, D182.2, D183.2, D184.2, D185.2, D186.2, D187.2, D188.2, D189.2, D190.2, D191.2, D192.2, P1.6
unnamed: D193.2, D194.2, D195.2, D196.2, D197.2, D198.2, D199.2, D200.2, D201.2, D202.2, D203.2, D204.2, D205.2, D206.2, D207.2, D208.2, D209.2, D210.2, D211.2, D212.2, D213.2, D214.2, D215.2, D216.2, D217.2, D218.2, D219.2, D220.2, D221.2, D222.2, D223.2, D224.2, P1.7
unnamed: D225.2, D226.2, D227.2, D228.2, D229.2, D230.2, D231.2, D232.2, D233.2, D234.2, D235.2, D236.2, D237.2, D238.2, D239.2, D240.2, D241.2, D242.2, D243.2, D244.2, D245.2, D246.2, D247.2, D248.2, D249.2, D250.2, D251.2, D252.2, D253.2, D254.2, D255.2, D256.2, P1.8
unnamed: D257.2, D258.2, D259.2, D260.2, D261.2, D262.2, D263.2, D264.2, D265.2, D266.2, D267.2, D268.2, D269.2, D270.2, D271.2, D272.2, D273.2, D274.2, D275.2, D276.2, D277.2, D278.2, D279.2, D280.2, D281.2, D282.2, D283.2, D284.2, D285.2, D286.2, D287.2, D288.2, P1.9
unnamed: D289.2, D290.2, D291.2, D292.2, D293.2, D294.2, D295.2, D296.2, D297.2, D298.2, D299.2, D300.2, D301.2, D302.2, D303.2, D304.2, D305.2, D306.2, D307.2, D308.2, D309.2, D310.2, D311.2, D312.2, D313.2, D314.2, D315.2, D316.2, D317.2, D318.2, D319.2, D320.2, P1.10
unnamed: D321.2, D322.2, D323.2, D324.2, D325.2, D326.2, D327.2, D328.2, D329.2, D330.2, D331.2, D332.2, D333.2, D334.2, D335.2, D336.2, D337.2, D338.2, D339.2, D340.2, D341.2, D342.2, D343.2, D344.2, D345.2, D346.2, D347.2, D348.2, D349.2, D350.2, D351.2, D352.2, P1.11
unnamed: D353.2, D354.2, D355.2, D356.2, D357.2, D358.2, D359.2, D360.2, D361.2, D362.2, D363.2, D364.2, D365.2, D366.2, D367.2, D368.2, D369.2, D370.2, D371.2, D372.2, D373.2, D374.2, D375.2, D376.2, D377.2, D378.2, D379.2, D380.2, D381.2, D382.2, D383.2, D384.2, P1.12
unnamed: D385.2, D386.2, D387.2, D388.2, D389.2, D390.2, D391.2, D392.2, D393.2, D394.2, D395.2, D396.2, D397.2, D398.2, D399.2, D400.2, D401.2, D402.2, D403.2, D404.2, D405.2, D406.2, D407.2, D408.2, D409.2, D410.2, D411.2, D412.2, D413.2, D414.2, D415.2, D416.2, P1.13
unnamed: D417.2, D418.2, D419.2, D420.2, D421.2, D422.2, D423.2, D424.2, D425.2, D426.2, D427.2, D428.2, D429.2, D430.2, D431.2, D432.2, D433.2, D434.2, D435.2, D436.2, D437.2, D438.2, D439.2, D440.2, D441.2, D442.2, D443.2, D444.2, D445.2, D446.2, D447.2, D448.2, P1.14
unnamed: D449.2, D450.2, D451.2, D452.2, D453.2, D454.2, D455.2, D456.2, D457.2, D458.2, D459.2, D460.2, D461.2, D462.2, D463.2, D464.2, D465.2, D466.2, D467.2, D468.2, D469.2, D470.2, D471.2, D472.2, D473.2, D474.2, D475.2, D476.2, D477.2, D478.2, D479.2, D480.2, P1.15
unnamed: D481.2, D482.2, D483.2, D484.2, D485.2, D486.2, D487.2, D488.2, D489.2, D490.2, D491.2, D492.2, D493.2, D494.2, D495.2, D496.2, D497.2, D498.2, D499.2, D500.2, D501.2, D502.2, D503.2, D504.2, D505.2, D506.2, D507.2, D508.2, D509.2, D510.2, D511.2, D512.2, P1.16
unnamed: D513.2, D514.2, D515.2, D516.2, D517.2, D518.2, D519.2, D520.2, D521.2, D522.2, D523.2, D524.2, D525.2, D526.2, D527.2, D528.2, D529.2, D530.2, D531.2, D532.2, D533.2, D534.2, D535.2, D536.2, D537.2, D538.2, D539.2, D540.2, D541.2, D542.2, D543.2, D544.2, P1.17
unnamed: D545.2, D546.2, D547.2, D548.2, D549.2, D550.2, D551.2, D552.2, D553.2, D554.2, D555.2, D556.2, D557.2, D558.2, D559.2, D560.2, D561.2, D562.2, D563.2, D564.2, D565.2, D566.2, D567.2, D568.2, D569.2, D570.2, D571.2, D572.2, D573.2, D574.2, D575.2, D576.2, P1.18
unnamed: D577.2, D578.2, D579.2, D580.2, D581.2, D582.2, D583.2, D584.2, D585.2, D586.2, D587.2, D588.2, D589.2, D590.2, D591.2, D592.2, D593.2, D594.2, D595.2, D596.2, D597.2, D598.2, D599.2, D600.2, D601.2, D602.2, D603.2, D604.2, D605.2, D606.2, D607.2, D608.2, P1.19
unnamed: D609.2, D610.2, D611.2, D612.2, D613.2, D614.2, D615.2, D616.2, D617.2, D618.2, D619.2, D620.2, D621.2, D622.2, D623.2, D624.2, D625.2, D626.2, D627.2, D628.2, D629.2, D630.2, D631.2, D632.2, D633.2, D634.2, D635.2, D636.2, D637.2, D638.2, D639.2, D640.2, P1.20
unnamed: D641.2, D642.2, D643.2, D644.2, D645.2, D646.2, D647.2, D648.2, D649.2, D650.2, D651.2, D652.2, D653.2, D654.2, D655.2, D656.2, D657.2, D658.2, D659.2, D660.2, D661.2, D662.2, D663.2, D664.2, D665.2, D666.2, D667.2, D668.2, D669.2, D670.2, D671.2, D672.2, P1.21
unnamed: D673.2, D674.2, D675.2, D676.2, D677.2, D678.2, D679.2, D680.2, D681.2, D682.2, D683.2, D684.2, D685.2, D686.2, D687.2, D688.2, D689.2, D690.2, D691.2, D692.2, D693.2, D694.2, D695.2, D696.2, D697.2, D698.2, D699.2, D700.2, D701.2, D702.2, D703.2, D704.2, P1.22
unnamed: D705.2, D706.2, D707.2, D708.2, D709.2, D710.2, D711.2, D712.2, D713.2, D714.2, D715.2, D716.2, D717.2, D718.2, D719.2, D720.2, D721.2, D722.2, D723.2, D724.2, D725.2, D726.2, D727.2, D728.2, D729.2, D730.2, D731.2, D732.2, D733.2, D734.2, D735.2, D736.2, P1.23
unnamed: D737.2, D738.2, D739.2, D740.2, D741.2, D742.2, D743.2, D744.2, D745.2, D746.2, D747.2, D748.2, D749.2, D750.2, D751.2, D752.2, D753.2, D754.2, D755.2, D756.2, D757.2, D758.2, D759.2, D760.2, D761.2, D762.2, D763.2, D764.2, D765.2, D766.2, D767.2, D768.2, P1.24
unnamed: D769.2, D770.2, D771.2, D772.2, D773.2, D774.2, D775.2, D776.2, D777.2, D778.2, D779.2, D780.2, D781.2, D782.2, D783.2, D784.2, D785.2, D786.2, D787.2, D788.2, D789.2, D790.2, D791.2, D792.2, D793.2, D794.2, D795.2, D796.2, D797.2, D798.2, D799.2, D800.2, P1.25
unnamed: D801.2, D802.2, D803.2, D804.2, D805.2, D806.2, D807.2, D808.2, D809.2, D810.2, D811.2, D812.2, D813.2, D814.2, D815.2, D816.2, D817.2, D818.2, D819.2, D820.2, D821.2, D822.2, D823.2, D824.2, D825.2, D826.2, D827.2, D828.2, D829.2, D830.2, D831.2, D832.2, P1.26
unnamed: D833.2, D834.2, D835.2, D836.2, D837.2, D838.2, D839.2, D840.2, D841.2, D842.2, D843.2, D844.2, D845.2, D846.2, D847.2, D848.2, D849.2, D850.2, D851.2, D852.2, D853.2, D854.2, D855.2, D856.2, D857.2, D858.2, D859.2, D860.2, D861.2, D862.2, D863.2, D864.2, P1.27
unnamed: D865.2, D866.2, D867.2, D868.2, D869.2, D870.2, D871.2, D872.2, D873.2, D874.2, D875.2, D876.2, D877.2, D878.2, D879.2, D880.2, D881.2, D882.2, D883.2, D884.2, D885.2, D886.2, D887.2, D888.2, D889.2, D890.2, D891.2, D892.2, D893.2, D894.2, D895.2, D896.2, P1.28
unnamed: D897.2, D898.2, D899.2, D900.2, D901.2, D902.2, D903.2, D904.2, D905.2, D906.2, D907.2, D908.2, D909.2, D910.2, D911.2, D912.2, D913.2, D914.2, D915.2, D916.2, D917.2, D918.2, D919.2, D920.2, D921.2, D922.2, D923.2, D924.2, D925.2, D926.2, D927.2, D928.2, P1.29
unnamed: D929.2, D930.2, D931.2, D932.2, D933.2, D934.2, D935.2, D936.2, D937.2, D938.2, D939.2, D940.2, D941.2, D942.2, D943.2, D944.2, D945.2, D946.2, D947.2, D948.2, D949.2, D950.2, D951.2, D952.2, D953.2, D954.2, D955.2, D956.2, D957.2, D958.2, D959.2, D960.2, P1.30
unnamed: D961.2, D962.2, D963.2, D964.2, D965.2, D966.2, D967.2, D968.2, D969.2, D970.2, D971.2, D972.2, D973.2, D974.2, D975.2, D976.2, D977.2, D978.2, D979.2, D980.2, D981.2, D982.2, D983.2, D984.2, D985.2, D986.2, D987.2, D988.2, D989.2, D990.2, D991.2, D992.2, P1.31
unnamed: D8.1, D40.1, D72.1, D104.1, D136.1, D168.1, D200.1, D232.1, D264.1, D296.1, D328.1, D360.1, D392.1, D424.1, D456.1, D488.1, D520.1, D552.1, D584.1, D616.1, D648.1, D680.1, D712.1, D744.1, D776.1, D808.1, D840.1, D872.1, D904.1, D936.1, D968.1, D1000.1, P2.8
unnamed: D993.2, D994.2, D995.2, D996.2, D997.2, D998.2, D999.2, D1000.2, D1001.2, D1002.2, D1003.2, D1004.2, D1005.2, D1006.2, D1007.2, D1008.2, D1009.2, D1010.2, D1011.2, D1012.2, D1013.2, D1014.2, D1015.2, D1016.2, D1017.2, D1018.2, D1019.2, D1020.2, D1021.2, D1022.2, D1023.2, D1024.2, P1.32
unnamed: D9.1, D41.1, D73.1, D105.1, D137.1, D169.1, D201.1, D233.1, D265.1, D297.1, D329.1, D361.1, D393.1, D425.1, D457.1, D489.1, D521.1, D553.1, D585.1, D617.1, D649.1, D681.1, D713.1, D745.1, D777.1, D809.1, D841.1, D873.1, D905.1, D937.1, D969.1, D1001.1, P2.9
unnamed: D11.1, D43.1, D75.1, D107.1, D139.1, D171.1, D203.1, D235.1, D267.1, D299.1, D331.1, D363.1, D395.1, D427.1, D459.1, D491.1, D523.1, D555.1, D587.1, D619.1, D651.1, D683.1, D715.1, D747.1, D779.1, D811.1, D843.1, D875.1, D907.1, D939.1, D971.1, D1003.1, P2.11
unnamed: D12.1, D44.1, D76.1, D108.1, D140.1, D172.1, D204.1, D236.1, D268.1, D300.1, D332.1, D364.1, D396.1, D428.1, D460.1, D492.1, D524.1, D556.1, D588.1, D620.1, D652.1, D684.1, D716.1, D748.1, D780.1, D812.1, D844.1, D876.1, D908.1, D940.1, D972.1, D1004.1, P2.12
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

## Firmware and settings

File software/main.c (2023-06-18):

#include "lowlevel/clock.h"
#include "lowlevel/uart.h"
#include "lowlevel/matrix_driver.h"

#include "frames_generator/frames_get.h"
#include "synchronize.h"

#include <libopencm3/stm32/gpio.h>


void vers_left(){
  uint32_t frame[MATRIX_SIZE];
  get_frame(frame,31);
  display_matrix(frame,100);
  get_frame(frame,34);
  display_matrix(frame,100);
  get_frame(frame,35);
  display_matrix(frame,100);
}

void ret_left(){
  uint32_t frame[MATRIX_SIZE];
  get_frame(frame,35);
  display_matrix(frame,100);
  get_frame(frame,34);
  display_matrix(frame,100);
  get_frame(frame,31);
  display_matrix(frame,100);
}

void vers_right(){
  uint32_t frame[MATRIX_SIZE];
  get_frame(frame,31);
  display_matrix(frame,100);
  get_frame(frame,32);
  display_matrix(frame,100);
  get_frame(frame,33);
  display_matrix(frame,100);
}

void ret_right(){
  uint32_t frame[MATRIX_SIZE];
  get_frame(frame,33);
  display_matrix(frame,100);
  get_frame(frame,32);
  display_matrix(frame,100);
  get_frame(frame,31);
  display_matrix(frame,100);
}

void ouvrir(){
  uint32_t frame[MATRIX_SIZE];
  for(int i=40;i>=36;i--){
    get_frame(frame,i);
    display_matrix(frame,75);
  }
}

void fermer(){
  uint32_t frame[MATRIX_SIZE];
  for(int i=36;i<41;i++){
    get_frame(frame,i);
    display_matrix(frame,75);
  }
}

void tatouage(){
  uint32_t frame[MATRIX_SIZE];
  for(int i=0;i<7;i++){
    get_frame(frame,i);
    display_matrix(frame,75);
  }
  for(int i=6;i>=0;i--){
    get_frame(frame,i);
    display_matrix(frame,75);
  }
}

void fire(){
  uint32_t frame[MATRIX_SIZE];
  for(int ix=0; ix<10; ix++){
     for(int i=7;i<15;i++){
      get_frame(frame,i);
      display_matrix(frame,20);
    }
  } 
}

void bonhomme(){
  uint32_t frame[MATRIX_SIZE];
  for(int i=19;i<31;i++){
    get_frame(frame,i);
    display_matrix(frame,50);
  }
  for(int i=30;i>=19;i--){
    get_frame(frame,i);
    display_matrix(frame,50);
  }
}

int main() {
  clock_setup();
  led_driver_setup();
  //uart_setup();

  //sync_init();


  uint32_t frame[MATRIX_SIZE];

  uint32_t frame_number = 0;
  uint32_t frame_count = get_frames_number();

  gpio_mode_setup(GPIOA,GPIO_MODE_OUTPUT, GPIO_PUPD_PULLDOWN, GPIO2);
  gpio_mode_setup(GPIOA,GPIO_MODE_OUTPUT, GPIO_PUPD_NONE, GPIO3);


  while (1) {
    //sync_resync();
    //sync_send();

    int real_frame;
    if (frame_number > frame_count) {
        real_frame = 2 * frame_count - frame_number;
    } else {
        real_frame = frame_number;
    }

/*
    get_frame(frame, real_frame);

    display_matrix(frame);
*/

    while(1){
      /* gauche
      vers_left();
      ret_left();
      vers_right();
      ret_right();
      */
     ouvrir();

      gpio_clear(GPIOA, GPIO3);
      get_frame(frame,31);
      while(gpio_get(GPIOA, GPIO2)!=0){
        display_matrix(frame,1);
      }
      display_matrix(frame,2);
      gpio_set(GPIOA, GPIO3);
      
      // uint32_t frame[MATRIX_SIZE];
      // get_frame(frame,13);
      // while (1)
      // {
      //   display_matrix(frame,15000);
      // }
      
      vers_right();
      ret_right();
      vers_left();
      ret_left();
      fermer();

      bonhomme();

      ouvrir();
      vers_right();
      ret_right();
      vers_left();
      ret_left();
      fermer();

      fire();

      ouvrir();
      vers_right();
      ret_right();
      vers_left();
      ret_left();
      fermer();

      tatouage();

      
    }

    // TODO we need to go through this loop more than once per frame ?

    frame_number = (frame_number + 1) % (frame_count*2);
  };

  return 0;
}

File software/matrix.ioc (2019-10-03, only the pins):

Mcu.UserName=STM32F303K8Tx
PA0.GPIO_Label=PURGE
PA0.Signal=GPIO_Output
PA1.GPIO_Label=BLANK
PA1.Signal=GPIO_Output
PA10.GPIO_Label=SERIAL_IN
PA10.Signal=GPIO_Output
PA11.GPIO_Label=CLK_COL
PA11.Signal=GPIO_Output
PA12.GPIO_Label=LATCH_COL
PA12.Signal=GPIO_Output
PA13.Signal=SYS_JTMS-SWDIO
PA14.Signal=SYS_JTCK-SWCLK
PA2.Signal=USART2_TX
PA3.Signal=USART2_RX
PA4.GPIO_Label=DATA
PA4.Signal=GPIO_Output
PA5.GPIO_Label=LINE_4
PA5.Signal=GPIO_Output
PA6.GPIO_Label=LINE_3
PA6.Signal=GPIO_Output
PA7.GPIO_Label=LINE_2
PA7.Signal=GPIO_Output
PB0.GPIO_Label=LINE_1
PB0.Signal=GPIO_Output
PB1.GPIO_Label=LINE_0
PB1.Signal=GPIO_Output

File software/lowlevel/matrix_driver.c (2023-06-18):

#include "matrix_driver.h"

#include "clock.h"

#include <libopencm3/stm32/rcc.h>
#include <libopencm3/stm32/gpio.h>

#define BLANK_Port_Lin     GPIOA
#define BLANK_Pin_Lin           GPIO0
#define BLANK_Port_Col     GPIOA
#define BLANK_Pin_Col           GPIO1
#define SERIAL_IN_Port_Lin GPIOB
#define SERIAL_IN_Pin_Lin       GPIO7
#define SERIAL_IN_Port_Col1 GPIOA
#define SERIAL_IN_Pin_Col1       GPIO8
#define CLK_Port_Col   GPIOA
#define CLK_Pin_Col         GPIO11
#define CLK_Port_Lin   GPIOB
#define CLK_Pin_Lin         GPIO6
#define LATCH_Port_Col GPIOA
#define LATCH_Pin_Col       GPIO12
#define LATCH_Port_Lin GPIOB
#define LATCH_Pin_Lin       GPIO5
#define CLEAR_Port_Lin GPIOA
#define CLEAR_Pin_Lin       GPIO4
#define CLEAR_Port_Col GPIOB
#define CLEAR_Pin_Col       GPIO1


const int boucleframe = 4000;

void led_driver_setup() {
  rcc_periph_clock_enable(RCC_GPIOA);
  rcc_periph_clock_enable(RCC_GPIOB);

  gpio_mode_setup(BLANK_Port_Lin,     GPIO_MODE_OUTPUT, GPIO_PUPD_NONE, BLANK_Pin_Lin);
  gpio_mode_setup(BLANK_Port_Col,     GPIO_MODE_OUTPUT, GPIO_PUPD_NONE, BLANK_Pin_Col);
  gpio_mode_setup(SERIAL_IN_Port_Lin,      GPIO_MODE_OUTPUT, GPIO_PUPD_NONE, SERIAL_IN_Pin_Lin);
  gpio_mode_setup(SERIAL_IN_Port_Col1,    GPIO_MODE_OUTPUT, GPIO_PUPD_NONE, SERIAL_IN_Pin_Col1);
  gpio_mode_setup(CLK_Port_Col,    GPIO_MODE_OUTPUT, GPIO_PUPD_NONE, CLK_Pin_Col);
  gpio_mode_setup(CLK_Port_Lin, GPIO_MODE_OUTPUT, GPIO_PUPD_NONE, CLK_Pin_Lin);
  gpio_mode_setup(LATCH_Port_Col,   GPIO_MODE_OUTPUT, GPIO_PUPD_NONE, LATCH_Pin_Col);
  gpio_mode_setup(LATCH_Port_Lin, GPIO_MODE_OUTPUT, GPIO_PUPD_NONE, LATCH_Pin_Lin);
  gpio_mode_setup(LATCH_Port_Col,   GPIO_MODE_OUTPUT, GPIO_PUPD_NONE, LATCH_Pin_Col);
  gpio_mode_setup(LATCH_Port_Lin, GPIO_MODE_OUTPUT, GPIO_PUPD_NONE, LATCH_Pin_Lin);
  gpio_mode_setup(CLEAR_Port_Lin,   GPIO_MODE_OUTPUT, GPIO_PUPD_NONE, CLEAR_Pin_Lin);
  gpio_mode_setup(CLEAR_Port_Col, GPIO_MODE_OUTPUT, GPIO_PUPD_NONE, CLEAR_Pin_Col);

  gpio_set(CLEAR_Port_Lin, CLEAR_Pin_Lin);
  gpio_set(CLEAR_Port_Col, CLEAR_Pin_Col);
  gpio_clear(BLANK_Port_Lin, BLANK_Pin_Lin);
  gpio_clear(BLANK_Port_Col, BLANK_Pin_Col);
}

void gpio_set_int(uint32_t gpioport, uint16_t gpios, int value) {
  (value & 1) ? gpio_set(gpioport, gpios) : gpio_clear(gpioport, gpios);
}



void select_line(uint32_t line) {
  // Sélection de la ligne
  gpio_clear(LATCH_Port_Col, LATCH_Pin_Col);
  gpio_clear(CLK_Port_Col, CLK_Pin_Col);
  if(line==0){
    gpio_set(SERIAL_IN_Port_Col1,SERIAL_IN_Pin_Col1);
  }
  else{
    gpio_clear(SERIAL_IN_Port_Col1,SERIAL_IN_Pin_Col1);
  }
  gpio_set  (CLK_Port_Col, CLK_Pin_Col);
}


void send_Col(uint32_t line) {
  gpio_clear(LATCH_Port_Lin, LATCH_Pin_Lin);

  for (int col = 0; col < 32; ++col) {
    gpio_clear(CLK_Port_Lin, CLK_Pin_Lin);
    gpio_set_int(SERIAL_IN_Port_Lin, SERIAL_IN_Pin_Lin, 1-(line >> (31-col)));
    gpio_set  (CLK_Port_Lin, CLK_Pin_Lin);
    
  }

  
}

void display_matrix_once(uint32_t matrix[MATRIX_SIZE]) {
  for (int line = 0; line < MATRIX_SIZE; ++line) {

    send_Col(matrix[line]);

    select_line(line);

    gpio_set(BLANK_Port_Col,BLANK_Pin_Col);
    delay_us(30);
    gpio_set(LATCH_Port_Lin, LATCH_Pin_Lin);
    gpio_set(LATCH_Port_Col, LATCH_Pin_Col);
    delay_us(10);
    gpio_clear(BLANK_Port_Col,BLANK_Pin_Col);
    
    
    



    
    //delay_ms(1);
    delay_us(100);
  }
}

void display_matrix(uint32_t matrix[MATRIX_SIZE],int frame_count) {
  for(int k = 0; k < frame_count; ++k) {
    display_matrix_once(matrix);
    delay_us(20);
  }
}

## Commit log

2015-10-01 structure minimale de projet
2015-10-01 enleve des blancs et corrige un oubli
2015-10-01 calcul de la frame à afficher fait séparément + display du texte comme il faut
2015-10-02 ajoute un fichier de font
2015-10-02 gestion de l'affichage de texte presque fonctionnel mais sale
2015-10-02 déplace les fonction, nettoyage à faire
2015-10-02 la génération du texte est faite à mesure
2015-10-02 utilise la vraie largeur de caractere
2015-10-03 adding framebuffer, sprites, key animation
2015-10-05 l'oeil diabolique est fini! Animations encore à fignoler. Ajout d'une fonction de dessin de sprites avec clipping ( afin de ne dessiner la pupille que dans l'oeil et pas en dehors).
2015-10-07 ajout du séquenceur de démos, du rendu de caractères, et commencement d'un scrolling text pouvant être chaîné avec un autre afficheur
2015-10-08 ajoute les routines hardware
2015-10-08 ajoute la fonction write_column()
2015-10-22 la simulation sur PC fonctionne ;)
2015-10-23 retournement des yeux pour PC
2019-10-03 New structure, pcbs
    [Carte OlINPiades 2017 - Logique.kicad_pcb, Carte OlINPiades 2017 - Logique.sch, Carte OlINPiades 2017 - Matrice.kicad_pcb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]
2019-10-03 new makefile
    [st_nucleo_f3.cfg]
2019-10-03 modif empreinte STM32
    [Carte OlINPiades 2017 - Logique.kicad_pcb, Carte OlINPiades 2017 - Logique.sch]
2019-10-03 modif marquage
    [Carte OlINPiades 2017 - Logique.kicad_pcb]
2019-10-03 ajout 3.3V pour esp
    [Carte OlINPiades 2017 - Logique.kicad_pcb, Carte OlINPiades 2017 - Logique.sch]
2019-10-03 Remove old files
    [gdb-pipe.cfg, st_nucleo_f303k8.cfg]
2019-10-03 Refactoring tree of git
    [gdb-pipe.cfg, st_nucleo_f3.cfg, st_nucleo_f4.cfg]
2019-10-03 fix build, remove warnings
    [main.c]
2019-10-04 Add new project, libopencm3 and clean code
    [gdb-pipe.cfg]
2019-10-04 Kicad 5, argh !
    [Carte OlINPiades 2017 - Logique.sch]
2019-10-04 begin frames generation and storage
2019-10-05 Integrate frames_generator into main proj
2019-10-05 Fix types, add weak for native tests.
    [uart.c]
2019-10-05 frame generation ok
2019-10-06 Update schematics and PCB to kicad5
    [Carte OlINPiades 2017 - Logique.kicad_pcb, Carte OlINPiades 2017 - Logique.sch]
2019-10-06 Port matrice to kicad 5
    [Carte OlINPiades 2017 - Matrice.kicad_pcb, Carte OlINPiades 2017 - Matrice.sch]
2019-10-08 Fix mirror, set debug by default, error on no libopencm3
    [main.c, matrix_driver.c]
2019-10-08 Add old frames generator code. The format should be converted from uint8[][] to uint32[].
2019-10-08 Remove old code
    [gdb-pipe.cfg, st_nucleo_f3.cfg, st_nucleo_f4.cfg]
2019-10-10 premiere version des yeux
2023-06-18 mise a jour important, nouvelle carte et programme, cumul des animations des derniers annee
    [Carte OlINPiades 2017 - Logique.kicad_pcb, Carte OlINPiades 2017 - Logique.sch, NouvelleCarteLogique.kicad_pcb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]
2023-06-18 changement de commit pour la librairie libopencm3
2023-06-18 changement de commit pour libopencm3 again...
2023-06-18 ajout des readme
